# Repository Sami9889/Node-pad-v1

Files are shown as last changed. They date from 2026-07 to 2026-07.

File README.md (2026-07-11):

# NodePad

> A tiny, cheap, more-powerful-than-a-Pi homelab node.
> Radxa CM5 (RK3588S2, 8-core, up to 16 GB RAM) on a **100 × 100 mm** carrier board with the kind of I/O a Pi 5 doesn't give you.

**Status:** Rev 0.1 placement/connectivity audit in progress — **not fabrication-ready; do not order**. See `VERIFICATION.md` for blocking footprint and pin-mapping defects.
**Author:** Samrath "Sami" Singh
**License:** TBD (MIT or CERN-OHL-P recommended if you plan to sell it)

---

## What is it?

A carrier board for the **Radxa CM5** compute module. You skip designing the CPU/RAM/eMMC section (Radxa already did that) and get a compact server-class SBC with I/O aimed at self-hosting, homelab, mini-Kubernetes, edge servers, network appliances, and NAS-lite.

Think of it as a **"buy 4, stack them, run K3s on PoE"** kind of board.

## Why not just buy a Pi 5?

| Feature | Pi 5 | Radxa CM5 + NodePad |
|---|---|---|
| CPU | 4× Cortex-A76 @ 2.4 GHz | **8×** (4×A76 + 4×A55) @ 2.4 GHz |
| GPU | VideoCore VII | **Mali-G610 MP4** (better) |
| NPU | ❌ | **6 TOPS** |
| Max RAM | 16 GB | 16 GB |
| Ethernet | 1× **1 GbE** | 2× **2.5 GbE** |
| NVMe | via HAT | **native M.2 M-key on board** |
| PoE | HAT (~$20) | **on-board (optional-populate)** |
| Boot | microSD | **eMMC on module** (no SD lottery) |

## Killer features (the pitch)

1. **Dual 2.5 GbE** — one built into the CM5, second added via the M.2 E-key slot with a 2.5GbE controller card *or* a discrete PHY on-board. Enough to run this thing as a router or a K3s node with dedicated cluster interconnect.
2. **M.2 M-key NVMe** slot (2280) — real SSDs, no microSD.
3. **PoE+ optional** — populate the PoE PD circuit and power it with a single Ethernet cable. Leave it unpopulated for cheap builds.
4. **USB-C PD input** — programmable trigger negotiates 12V/15V/20V from any PD charger. No barrel jack, no wall wart headache.
5. **100 × 100 mm square** — cheapest JLCPCB tier, fits in a 3D-printed cube smaller than a Pi 5.

## Cost target

| Version | BOM cost (qty 10) | Sell target |
|---|---|---|
| **Base** (no PoE) | ~$40 empty board | **$99** empty / **$189** with CM5 8GB |
| **Full** (with PoE) | ~$55 empty board | **$129** empty / **$219** with CM5 8GB |

Comparable products: Turing Pi 2 ($260, but 4-node), Radxa Rock 5A ($90 SBC, no PoE/NVMe boot), DeskPi Super6C ($200, Pi CM4-only). NodePad's niche = smallest + PoE + cheap single node.

---

## Bill of Materials (JLCPCB / LCSC part numbers)

All parts picked to be **in JLCPCB's Basic or Extended library** so the whole board can be assembled by JLC PCBA (no hand-soldering headaches). Prices approximate as of 2026-07.

### Compute
| Ref | Part | Function | LCSC | Qty | Price ea. |
|---|---|---|---|---|---|
| U1 | Radxa CM5 (8 GB / 64 GB) | System-on-module | — (Radxa direct) | 1 | **$89** |
| J1, J2 | Hirose DF40C-100DS-0.4V | 2× 100-pin SoM connectors | C43880 | 2 | $2.50 |

### Networking
| Ref | Part | Function | LCSC | Qty | Price ea. |
|---|---|---|---|---|---|
| U2 | RTL8125BG | 2.5GbE MAC+PHY (2nd NIC) | C2861126 | 1 | $3.10 |
| J3, J4 | Bel Fuse 0826-1G1T-04-F | RJ45 with integrated magnetics + LEDs, PoE-capable | C516428 | 2 | $2.80 |
| Y1 | 25 MHz TCXO 3.3V 20ppm | RTL8125 clock reference | C1804 | 1 | $0.30 |

### Storage
| Ref | Part | Function | LCSC | Qty | Price ea. |
|---|---|---|---|---|---|
| J5 | M.2 M-key 2280 socket | NVMe SSD slot | C725119 | 1 | $1.20 |
| J6 | M.2 E-key 2230 socket | WiFi/BT card or 2nd NIC | C725118 | 1 | $0.95 |

### Power
| Ref | Part | Function | LCSC | Qty | Price ea. |
|---|---|---|---|---|---|
| U3 | MP2315 | 5V @ 3A buck (main rail from 12V PD) | C89358 | 1 | $0.42 |
| U4 | AP2112K-3.3 | 3.3V @ 600 mA LDO (rail for RTC, aux) | C51118 | 1 | $0.20 |
| U5 | CH224K | USB-C PD sink, programmable 5/9/12/15/20V | C970725 | 1 | $0.55 |
| U6 *(opt)* | MP8007GV | PoE+ PD converter (802.3at, 25W) | C910435 | 1 | $2.80 |
| T1 *(opt)* | 750317847 or eq. | PoE flyback transformer | C — | 1 | $2.20 |

### I/O
| Ref | Part | Function | LCSC | Qty | Price ea. |
|---|---|---|---|---|---|
| J7 | USB-C 16-pin recept. | Power in + USB 2.0 data | C165948 | 1 | $0.35 |
| J8–J11 | USB-A 3.0 vertical | 4× USB 3.0 host ports | C165999 | 4 | $0.55 |
| J12 | HDMI Type-A | HDMI 2.0 out | C2681 | 1 | $0.60 |
| J13 | 40-pin 2.54 mm header | Pi-compatible GPIO | C124378 | 1 | $0.25 |
| J14 | microSD push-push socket | Boot fallback | C91145 | 1 | $0.45 |
| J15 | 4-pin 2.54 mm header | PWM fan | C124381 | 1 | $0.15 |

### Housekeeping
| Ref | Part | Function | LCSC | Qty | Price ea. |
|---|---|---|---|---|---|
| U7 | DS3231MZ+ | I²C RTC (server needs to know time on cold boot) | C107373 | 1 | $2.10 |
| BT1 | CR2032 SMD holder | RTC coin cell | C70376 | 1 | $0.28 |
| U8, U9 | USBLC6-2SC6 | USB ESD/TVS | C7469 | 2 | $0.16 |
| SW1 | Momentary 6×6 mm tact | Reset button | C318884 | 1 | $0.08 |
| SW2 | Momentary 6×6 mm tact | Boot/recovery button | C318884 | 1 | $0.08 |
| D1–D5 | 0603 green/red LEDs | Power, activity, link, status | C72043 | 5 | $0.03 |
| — | Passives (R, C, L, ferrites) | ~120 in total, 0402/0603 | JLC Basic | — | ~$3 total |

### PCB
| Item | Spec | Price (qty 10 at JLCPCB) |
|---|---|---|
| 4-layer PCB, 100 × 100 mm, ENIG, black soldermask | Standard stackup, 1 oz Cu | ~$25 total ($2.50/board) |
| JLC PCBA (all SMD assembled) | 1-side, standard | ~$8/board |

### Rolled-up cost per finished board (qty 10)

| Version | PCB | PCBA | Components (per board) | **Empty PCB total** | Add CM5 8GB | **All-in** |
|---|---|---|---|---|---|---|
| Base (no PoE) | $2.50 | $8 | ~$26 | **~$36.50** | +$89 | **$125.50** |
| Full (with PoE) | $2.50 | $9 | ~$32 | **~$43.50** | +$89 | **$132.50** |

Room to sell base @ **$99 (empty PCB only)** or **$199 (with 8GB CM5 pre-installed)** and still keep ~40% margin. 🎯

---

## Block diagram

```
                        ┌──────────────────────────────────┐
                        │      Radxa CM5 (RK3588S2)        │
                        │  8-core • 8GB LPDDR4X • 64GB eMMC│
                        │  Native: 1 GbE, HDMI, USB3.0,    │
                        │  PCIe 2.1 x1, MIPI-DSI/CSI, GPIO │
                        └──┬───┬───┬───┬───┬───┬───┬───────┘
                           │   │   │   │   │   │   │
              ┌────────────┘   │   │   │   │   │   └──────────────┐
              │                │   │   │   │   │                  │
        ┌─────▼─────┐    ┌─────▼─┐ │   │   │ ┌─▼──────┐   ┌───────▼─────┐
        │ RTL8125BG │    │ RJ45  │ │   │   │ │ HDMI 2.0│   │ 40-pin GPIO │
        │  2.5 GbE  │◄──►│ #1 PoE│ │   │   │ └─────────┘   │  Pi-compat  │
        │  (2nd NIC)│    │ 1 GbE │ │   │   │               └─────────────┘
        └─────┬─────┘    └───────┘ │   │   │
              │                    │   │   │
         ┌────▼────┐            ┌──▼─┐ │  ┌▼─────────┐
         │  RJ45 #2│            │M.2 │ │  │ 4× USB   │
         │ 2.5 GbE │            │E-key│ │  │ 3.0 A   │
         │ (opt PoE│            │2230 │ │  └──────────┘
         │  input) │            │(WiFi│ │
         └────┬────┘            │/NIC)│ │
              │                 └─────┘ │
         ┌────▼──────┐         ┌────────▼─┐
         │ MP8007 PoE│         │ M.2 M-key│
         │  PD (opt) │         │  2280    │
         └────┬──────┘         │  NVMe    │
              │                └──────────┘
        ┌─────▼─────┐    ┌──────────────┐   ┌───────────┐
        │ CH224K PD │◄───│  USB-C in    │   │ DS3231 RTC│
        │  trigger  │    │ (5/12/20V)   │   │ +CR2032   │
        └─────┬─────┘    └──────────────┘   └───────────┘
              │
        ┌─────▼──────┐
        │ MP2315 buck│──► 5V rail (CM5, USB, fan, etc.)
        │ + AP2112   │──► 3.3V aux (RTC, LEDs, logic)
        └────────────┘
```

## Repo layout (planned)

```
nodepad/
├── README.md                (this file)
├── DESIGN.md                (deep design rationale, pin assignments, DRC rules)
├── BOM.csv                  (machine-readable, for JLC PCBA upload)
├── PCB/                     (KiCad 10 project)
│   ├── NodePad.kicad_pro
│   ├── NodePad.kicad_sch    (multi-sheet: cpu, network, power, io)
│   └── NodePad.kicad_pcb
├── CAD/                     (case: front, back, mount plate)
│   └── nodepad-case.step
├── Production/
│   ├── gerbers.zip
│   ├── bom.csv              (JLC PCBA format)
│   ├── cpl.csv              (component placement)
│   └── assembly-drawings.pdf
├── Firmware/                (bootloader configs, device tree overlay if needed)
└── docs/
    └── quick-start.md
```

---

## Two variants

| | **NodePad** (base) | **NodePad-Net** (networking) |
|---|---|---|
| **Compute** | Radxa CM5 (8-core RK3588S2 + Mali-G610 GPU + 6 TOPS NPU) | Same |
| **Ethernet** | 1× 1 GbE (native) + 1× 2.5 GbE (RTL8125) | 1× 1 GbE + **2× 2.5 GbE** (2× RTL8125) |
| **Fiber** | — | **1× SFP cage** (1G SGMII) |
| **NVMe** | 1× M.2 M-key 2280 | 1× M.2 M-key 2280 |
| **WiFi slot** | 1× M.2 E-key 2230 | ❌ (PCIe1 used for 2nd NIC) |
| **HDMI** | 1× HDMI 2.0 | ❌ (headless appliance) |
| **USB** | 4× USB-A 3.0 (GL3523 hub) | 2× USB-A 3.0 |
| **PoE** | Footprint-only (DNP) | Footprint-only (DNP) |
| **Netlist stats** | 230 comps, 239 nets, 0 ERC errors | 219 comps, 227 nets, 0 ERC errors |
| **Sell target** | $99 empty / $199 with CM5 | $129 empty / $229 with CM5 |

Both share the same 100 × 100 mm 4-layer PCB scaffold; the SKiDL blocks
compose differently to build each variant's netlist.

### About the CPU + GPU

The CPU (8-core Cortex-A76/A55) and GPU (Mali-G610 MP4) live **on the
Radxa CM5 module itself** — we don't design them into the carrier
board. That's the entire point of using a SoM: you buy the pre-built
compute module for $89 and skip the ~$1000-per-chip BGA design effort.
The carrier board's job is just to break out the CM5's I/O to the
connectors, feed it power, and add the peripherals (Ethernet, USB,
NVMe, SFP, etc.).

---

| # | Decision | Choice |
|---|---|---|
| 1 | **PoE** | Footprint-only (populate optional) |
| 2 | **HDMI** | Kept |
| 3 | **2nd 2.5 GbE NIC** | On-board RTL8125BG (biggest diff vs Pi 5) |
| 4 | **USB 3.0 ports** | 4× vertical Type-A (via GL3523 hub) |
| 5 | **License** | CERN-OHL-P v2 |

---

## Next steps (in order)

- [x] Design brief locked
- [x] KiCad 10 project scaffold created (`/PCB/NodePad.kicad_pro`, `.kicad_sch`, `.kicad_pcb`)
- [x] 100 × 100 mm board outline with 4× M2.5 mounting holes
- [x] 4-layer stackup + JLC-tuned design rules + net classes (PCIe / USB3 / Ethernet / HDMI / Power)
- [x] BOM.csv with LCSC part numbers
- [x] LICENSE (CERN-OHL-P v2)
- [ ] Schematic capture — power tree
- [ ] Schematic capture — CM5 SoM connectors + decoupling
- [ ] Schematic capture — RTL8125 NIC + magnetics
- [ ] Schematic capture — M.2 M-key + E-key slots
- [ ] Schematic capture — GL3523 USB 3.0 hub + 4× USB-A
- [ ] Schematic capture — HDMI, GPIO header, RTC, buttons, LEDs
- [ ] Schematic capture — PoE section (footprint-only, DNP)
- [ ] ERC clean
- [ ] Footprint assignment (JLC-Basic priority)
- [ ] PCB placement
- [ ] PCB routing (PCIe → USB3 → HDMI → Ethernet → GPIO)
- [ ] DRC clean
- [ ] Gerber + CPL + BOM export
- [ ] Order 5 prototypes from JLCPCB (~$400)
- [ ] Bring-up + rev 2 fixes
- [ ] Sellable rev 2 spin

Realistic total timeline from your side: **~3 months part-time** to a rev-2 sellable board. My share (design + docs) is front-loaded in the first 2–3 weeks.

---

## Honest disclaimer

I can draft the schematic + rough PCB layout in KiCad and give you a starting point you can iterate on. **High-speed routing (2.5GbE differential pairs, PCIe Gen 2, USB 3.0)** benefits massively from human review before you spend money on prototypes — it's not the kind of thing to click "generate" and ship. Plan for at least **one rev-2 spin** to fix the bugs the first prototype reveals. Every serious hardware product does this.

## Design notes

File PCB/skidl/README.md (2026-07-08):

# NodePad — SKiDL Schematic Source (FULL DESIGN)

The full schematic is authored as Python using [SKiDL](https://github.com/devbisme/skidl).
Running `main.py` produces a KiCad netlist that imports directly into
`../NodePad.kicad_pcb` and drops every footprint onto the board with all
ratsnest connections pre-wired.

## Files

| File | Contents | Status |
|---|---|---|
| `power_tree.py` | USB-C → CH224K PD → MP2315 buck (5V) → AP2112 LDO (3.3V), ESD, test points | ✅ pin-verified |
| `rtc.py` | DS3231MZ+ RTC with CR2032 backup, I²C pull-ups | ✅ pin-verified |
| `user_io.py` | SW1/SW2 buttons, D1–D5 LEDs, J13 GPIO 40-pin, J15 fan header | ✅ pin-verified |
| `cm5.py` | 2× DF40 100-pin SoM connectors + 5V decoupling (16 caps) | ⚠️ TODO_VERIFY pin map vs Radxa datasheet |
| `ethernet.py` | RJ45 #1 (1G native), RJ45 #2 + RTL8125BG (2.5G) + Bob-Smith term | ⚠️ TODO_VERIFY RTL8125 pins |
| `usb_hub.py` | GL3523 hub + 4× USB-A + 4× TPS2553 current-limit switches | ⚠️ TODO_VERIFY GL3523 pins |
| `m2.py` | M.2 M-key 2280 NVMe + M.2 E-key 2230 WiFi with PCIe wiring | ⚠️ TODO_VERIFY PCIe pins |
| `hdmi.py` | HDMI Type-A jack, 4× USBLC6 ESD, series R + level-shift stubs | ⚠️ TODO_VERIFY HDMI diff pairs |
| `poe.py` | PoE+ front-end: bridge rectifier, TVS, MP8007, isolation transformer (all DNP) | ⚠️ TODO_VERIFY MP8007 pins |
| `extras.py` | HDMI DDC level shifter (BSS138 x2), heatsink mount posts, extra decoupling, EMI cap | ✅ standard patterns |
| `main.py` | Wires everything together into one design and emits `netlists/nodepad.net` | ✅ 0 ERC errors |

## Current netlist stats

- **230 components** placed
- **239 nets** wired
- **36 unique footprints**, all from stock KiCad 9 library
- All footprints are JLCPCB PCBA compatible
- **0 ERC errors** (219 warnings, all about unconnected GPIO header pins
  and expected TODO_VERIFY placeholders)

## Prerequisites

```bash
pip install skidl==2.2.3
git clone --depth 1 --branch 9.0.0 \
    https://gitlab.com/kicad/libraries/kicad-symbols.git \
    ~/kicad-symbols
export KICAD_SYMBOL_DIR=~/kicad-symbols
export KICAD9_SYMBOL_DIR=~/kicad-symbols
```

## Generate the netlist

```bash
cd PCB/skidl
python3 main.py
# → netlists/nodepad.net
```

## Import into KiCad PCB

1. Open `PCB/NodePad.kicad_pcb` in KiCad 10.
2. **File → Import → KiCad Netlist**
3. Point it at `PCB/skidl/netlists/nodepad.net`
4. Match by **Reference**, Update fields ON, Delete extras ON.
5. Click **Update PCB**. All 230 footprints drop onto the board.

## ⚠️ CRITICAL: Fab-safety checklist before ordering silicon

Every file with **⚠️ TODO_VERIFY** above uses **placeholder pin numbers**
for the chip in question. You MUST review each of the following against
the official datasheet before ordering PCBs:

| Chip | Datasheet source | Pins to verify |
|---|---|---|
| Radxa CM5 | https://docs.radxa.com/en/som/cm/cm5/hardware/hardware-interface | All 200 pins (2× DF40) |
| RTL8125BG | Realtek RTL8125 datasheet | PCIe pairs, MDI pairs, VCC, LEDs |
| GL3523 | Genesys Logic GL3523 datasheet | USB SS pairs, HS pairs, straps |
| MP2315 | MPS MP2315 datasheet | SW/BST/FB/EN/COMP wiring |
| MP8007 | MPS MP8007 datasheet | RCLASS, SW node, feedback |
| CH224K | WCH CH224K datasheet | CFG resistor pattern for 12V |
| DDC line level shifter | If shipping to modern displays, upgrade to TXS0102 | — |

**Rev-1 will have bugs.** Budget for a rev-2 spin. Every SBC design in
history has needed at least one rework — this is normal, not a failure.

## What each block actually does

### `power_tree.py`
USB-C plug → CH224K negotiates 12V from PD charger → MP2315 buck steps
that down to 5V @ 3A (main CM5 rail) → AP2112 LDO drops 5V to 3.3V for
low-current logic (RTC, LEDs, PHY idle).

### `cm5.py`
Fans out the 100-pin DF40 SoM connectors J1 and J2 into named nets that
the rest of the design uses. This is the "hub" of the schematic — if
these pin assignments are wrong, nothing works.

### `ethernet.py`
Two Ethernet ports. RJ45 #1 uses the CM5's native 1 GbE PHY. RJ45 #2
gets a discrete RTL8125BG chip that talks PCIe Gen 2 x1 to the CM5's
Combo1 lane and does 2.5 GbE off its own PHY.

### `usb_hub.py`
The CM5 has one native USB 3.0 host, but we want 4× USB-A. GL3523 is a
4-port USB 3.0 hub that fans that single port out. Each downstream port
gets its own TPS2553 power switch so a shorted USB device can't take
down the whole board.

### `m2.py`
Two M.2 slots. J5 is the big M-key 2280 slot for NVMe SSDs — this is
where OS boot storage lives. J6 is the smaller E-key 2230 slot for
WiFi/BT modules (or a 2nd 2.5 GbE NIC card if you want to skip WiFi).

### `hdmi.py`
Standard HDMI 2.0 output. TMDS pairs are AC-coupled inside the CM5 so
they route straight through. DDC (I²C to talk EDID with the display) is
level-shifted 3.3V→5V by the BSS138 pair in `extras.py`. All 4 diff
pairs get USBLC6 ESD protection.

### `poe.py`
Optional PoE+ input. **All parts DNP by default** — populate only if you
want PoE. Uses MP8007 as the PD interface controller with a Wurth
750317847 flyback transformer to isolate the ~48V PoE from the 12V
system rail. Meets 802.3at (Class 4, 25 W).

### `rtc.py`
DS3231 real-time clock with a CR2032 coin cell backup. When the board
loses power, the RTC keeps time on the coin cell (~5-year life). Critical
for a server that needs correct time immediately on boot without waiting
for NTP.

### `user_io.py`
Reset button (SW1) pulls CM5 RUN# to GND. Boot/recovery button (SW2)
pulls maskrom pin. Five LEDs: Power, System, Link 1, Link 2, NVMe
activity. 4-pin PWM fan header. 40-pin Pi-compatible GPIO header for HATs.

### `extras.py`
Belt-and-braces: 22 more 100nF decoupling caps distributed across the
5V and 3.3V rails, 7 more 10 µF bulk caps, 4× ferrite beads on sensitive
analog supplies (HDMI, PCIe, both ETH PHYs), 4× M2.5 heatsink mounting
holes near the CM5, the HDMI DDC level shifter, and a 1nF/2kV EMI cap
between signal GND and chassis GND.

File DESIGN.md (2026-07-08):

# NodePad — Deep Design Document

Detailed engineering rationale, pin assignments, and layout guidance.
Companion to `README.md` (the marketing/overview doc).

**Revision:** 0.1 (pre-schematic)
**Target SoM:** Radxa CM5 (RK3588S2), 8 GB LPDDR4X, 64 GB eMMC
**PCB stackup:** 4 layers, JLCPCB standard, 1 oz Cu, 1.6 mm thickness
**Board size:** 100 × 100 mm (cheapest JLC tier)

---

## 1. Locked-in decisions

| # | Decision | Choice | Rationale |
|---|---|---|---|
| 1 | PoE circuit | Footprint-only (DNP by default) | Adds ~$8 BOM; make it opt-in for buyers who need it |
| 2 | HDMI | Kept | Costs $1.20; useful for initial setup + hobbyists |
| 3 | 2nd 2.5 GbE NIC | On-board RTL8125BG | Biggest differentiator vs. Pi 5 |
| 4 | USB 3.0 ports | 4× vertical Type-A | Matches Pi 5, useful for NAS builds |
| 5 | License | CERN-OHL-P v2 | Permissive open-hardware, allows commercial |

---

## 2. Radxa CM5 pinout summary

Radxa CM5 uses **2× 100-pin Hirose DF40C-100DS-0.4V** connectors on the underside (0.4 mm pitch, 1.5 mm mated height), matching the Pi CM4 mechanical footprint. Signals differ from CM4 — do NOT reuse CM4 carrier layouts blindly.

**Full pinout reference:** [docs.radxa.com/en/som/cm/cm5](https://docs.radxa.com/en/som/cm/cm5)

Critical signal groups on the CM5:

| Group | Count | Where they go on NodePad |
|---|---|---|
| Power in (5 V) | 6 pins | From MP2315 buck (5V @ 3A) |
| Power in (3.3 V logic) | Internal on module | — |
| GND | 30+ pins | Solid ground pour |
| **PCIe 2.1 x1 (Combo0)** | 4 diff pairs + REFCLK + REFCLK_N + CLKREQ# + PERST# + WAKE# | → **M.2 M-key NVMe** |
| **PCIe 2.1 x1 (Combo1)** *(optional lane)* | Same as above | → **M.2 E-key** (WiFi/2nd NIC) |
| USB 3.0 host | 1× SS RX/TX pair + USB 2.0 pair | → USB 3.0 hub or direct to USB-A #1 |
| USB 2.0 host x2 | 2 pairs | → 40-pin GPIO breakout + USB-A #2 |
| USB 2.0 OTG | 1 pair | → USB-C data (shared with power in) |
| **GbE (native)** | RGMII or SGMII to internal PHY, MDIO/MDC, 4 diff pairs | → RJ45 #1 |
| I²C0/1/3/5 | Multiple | RTC, GPIO header, expansion |
| SPI0/3 | Multiple | GPIO header |
| UART0 (console) | TX/RX | Debug pin header |
| UART2/3/6/8 | RX/TX | GPIO header |
| PWM 0-14 | Various | Fan header (PWM12), GPIO |
| HDMI TX | 3 diff pairs + clock + HPD + CEC + DDC | → HDMI Type-A jack |
| MIPI-DSI (LCD) | 4 lanes + clock | NOT USED (avoid, keep pins free) |
| MIPI-CSI (camera) | 2× ports, 4 lanes each | NOT USED (avoid) |
| SD card | CMD, CLK, DAT0-3 | → microSD push-push socket |
| Boot select | 3-4 pins | → jumper block for eMMC vs SD boot |
| GPIO 40 | GPIO 0-27 | → 40-pin Pi-compatible header |
| Reset | RUN# / RESET# | → SW1 momentary |
| Recovery/Maskrom | ~1 pin | → SW2 momentary |

---

## 3. Peripheral pin assignments (planned)

### 3.1 Power tree

```
USB-C VBUS (5V or PD 5/9/12/15/20V)
        │
        ▼
   CH224K (PD sink; hardcoded 12V request via CFG resistors)
        │
        ▼
   VIN_12V bus  ── to PoE input path (footprint-only)
        │
        ▼
   MP2315 buck → 5V @ 3A ── to CM5 (6 pins), USB hub, fan, LEDs
        │
        ▼
   AP2112K-3.3 LDO → 3.3V_AUX @ 600 mA ── to RTC, RTL8125 idle, logic
```

Total budget:
- Radxa CM5 (worst case, all-cores loaded + NPU): ~9 W → 1.8 A @ 5 V
- NVMe SSD: up to 3 W → 0.6 A @ 5 V
- RTL8125 NIC: ~0.5 W → 0.1 A @ 3.3 V
- USB 3.0 devices (4 ports @ 900 mA each worst-case): 3.6 A @ 5 V (add TPS2553 current limiters — see BOM)
- Total peak: **~15 W** at 5 V → USB-C PD 20 V @ 1 A is safe (fits in 15 W PD profile)

### 3.2 Networking

**NIC #1 (native CM5 GbE PHY, upgraded to 2.5 G later? No — RK3588S PHY is 1 G, use as GbE):**
- Actually route CM5's native GBE_ interface to RJ45 #1 via magnetics
- 4 diff pairs: TXP0/N0, TXP1/N1, TXP2/N2, TXP3/N3 → length matched within 50 mil, 100 Ω differential

Wait — RK3588S has *one* native GbE PHY only. For **dual 2.5 GbE** we need to run **PCIe → RTL8125** for the 2nd port. Decision:

- **RJ45 #1**: CM5 native GbE (1 Gbps) — cheap, always populated
- **RJ45 #2**: RTL8125BG over PCIe 2.1 x1 (2.5 Gbps) — this is the "faster than Pi 5" claim

If we want **dual 2.5 GbE**, add a 2nd RTL8125 to the Combo1 lane at the cost of the M.2 E-key WiFi slot. For rev 1, ship as (1G + 2.5G) which is still better than Pi 5 (single 1G).

**Ethernet magnetics + jack:** Use integrated-magnetics RJ45 (Bel Fuse 0826-1G1T or Halo HFJ11-2450). Center taps → 75Ω Bob Smith termination + 1kV cap to chassis GND.

### 3.3 M.2 slots

- **J5 M-key (2280)**: 4-pin PCIe (Rx±, Tx±) + REFCLK diff pair + PERST# + CLKREQ# + WAKE# → CM5's PCIe Combo0. Standard NVMe pinout. 3.3 V power @ 3 A via dedicated buck if we're paranoid (Pi 5 problem — under-volts on some SSDs). Solution: use MP2315 rail at 3.3 V for M.2 only.
- **J6 E-key (2230)**: 4-pin PCIe (from Combo1) + USB 2.0 pair (from CM5 spare) + I²C + LED + control. Standard WiFi module pinout. 3.3 V power.

### 3.4 USB

CM5 has: 1× USB 3.0 host, 2× USB 2.0 host, 1× USB 2.0 OTG.

For **4× USB-A 3.0** we need a **USB 3.0 hub IC**. Options:
- **GL3523** (Genesys Logic, 4-port USB 3.0 hub) — LCSC C107837, ~$1.80. Popular in Pi HATs.
- **TUSB4041** (TI) — more expensive but rock-solid.

**Decision:** GL3523. Feed it from CM5 USB 3.0 host, output 4× USB-A downstream. Add **4× TPS2553 current limiters** ($0.35 each) for per-port over-current protection.

USB 2.0 ports on CM5:
- Port 0 → OTG → USB-C (shared with power)
- Port 1 → 40-pin GPIO breakout (headers only, for expansion HATs)
- Port 2 → available (route to internal test point or drop)

### 3.5 HDMI

CM5 has HDMI 2.0 TX with 3 diff pairs (TMDS0/1/2) + clock pair + DDC (I²C SDA/SCL) + HPD + CEC.

- Route all 4 diff pairs, length-match within 5 mil, 100 Ω differential
- Add ESD protection: 5 lines × PESD1CAN or similar TVS array
- HDMI Type-A jack: full-size (Molex 47151-1005 or LCSC C2681)

### 3.6 GPIO 40-pin header

Standard **Raspberry Pi HAT-compatible** pinout. Route to `J13`. Pinout mapping:

| Pin | Function | CM5 GPIO |
|---|---|---|
| 1 | 3.3V | — |
| 2 | 5V | — |
| 3 | I²C1 SDA | GPIO1_D0 |
| 4 | 5V | — |
| 5 | I²C1 SCL | GPIO1_D1 |
| 6 | GND | — |
| 7 | GPIO4 | GPIO1_A0 |
| 8 | UART2 TX | GPIO0_B5 |
| 9 | GND | — |
| 10 | UART2 RX | GPIO0_B6 |
| 11 | GPIO17 | GPIO1_A1 |
| 12 | PWM0 | GPIO1_A2 |
| 13 | GPIO27 | GPIO1_A3 |
| 14 | GND | — |
| 15 | GPIO22 | GPIO1_A4 |
| 16 | GPIO23 | GPIO1_A5 |
| 17 | 3.3V | — |
| 18 | GPIO24 | GPIO1_A6 |
| 19 | SPI0 MOSI | GPIO4_B2 |
| 20 | GND | — |
| 21 | SPI0 MISO | GPIO4_B0 |
| 22 | GPIO25 | GPIO1_A7 |
| 23 | SPI0 SCLK | GPIO4_B3 |
| 24 | SPI0 CE0 | GPIO4_B1 |
| 25 | GND | — |
| 26 | SPI0 CE1 | GPIO4_B7 |
| 27 | I²C0 SDA | GPIO4_A0 |
| 28 | I²C0 SCL | GPIO4_A1 |
| 29 | GPIO5 | GPIO4_A2 |
| 30 | GND | — |
| 31 | GPIO6 | GPIO4_A3 |
| 32 | PWM1 | GPIO4_A4 |
| 33 | PWM2 | GPIO4_A5 |
| 34 | GND | — |
| 35 | GPIO19 | GPIO4_A6 |
| 36 | GPIO16 | GPIO4_A7 |
| 37 | GPIO26 | GPIO4_B4 |
| 38 | GPIO20 | GPIO4_B5 |
| 39 | GND | — |
| 40 | GPIO21 | GPIO4_B6 |

*Numbers in "CM5 GPIO" column are provisional — confirm against Radxa datasheet before final routing.*

### 3.7 RTC

DS3231MZ+ (I²C, TCXO, ±5 ppm) on I²C bus shared with system I²C0. Coin cell CR2032 in BT1.
Backup current draw: ~3 µA → ~5-year life on a CR2032.

### 3.8 Fan header

4-pin PC-style header (Molex Mini KK):
1. GND
2. +5V (or +12V if we route from PoE/PD input directly)
3. TACH → CM5 GPIO (input, needs pull-up)
4. PWM (25 kHz) → CM5 PWM12

### 3.9 Buttons + LEDs

- **SW1 Reset**: pulls CM5 RUN# to GND (active low)
- **SW2 Boot**: pulls Maskrom/recovery pin to appropriate level (verify with Radxa datasheet — often GND during power-on)
- **D1 PWR**: green, 3.3V rail
- **D2 SYS**: user-programmable (GPIO)
- **D3 LINK1**: RJ45 #1 link (from PHY)
- **D4 LINK2**: RJ45 #2 link (from RTL8125)
- **D5 NVMe**: activity LED (from M.2 J5 pin 11)

---

## 4. PCB layout strategy (100 × 100 mm)

### 4.1 Component placement zones

```
┌─────────────────────────────────────────────┐
│  RJ45 #1 (1G) │ RJ45 #2 (2.5G) │  USB-C    │  ← REAR I/O EDGE
├─────────────────────────────────────────────┤
│                                             │
│  M.2 E-key (2230)                           │
│  ─────────                                  │
│                                             │
│  ┌──────────────────┐                       │
│  │                  │       HDMI            │
│  │   Radxa CM5      │       USB-A x4        │
│  │   (top center)   │       (right edge)    │
│  │                  │                       │
│  └──────────────────┘                       │
│                                             │
│  M.2 M-key (2280) NVMe                      │
│  ────────────────────────────               │
│                                             │
├─────────────────────────────────────────────┤
│  Power (MP2315, CH224K, AP2112)             │
│  RTC + coin cell    | 40-pin GPIO header    │  ← FRONT EDGE
└─────────────────────────────────────────────┘
```

### 4.2 Layer stackup (JLCPCB standard 4-layer)

| Layer | Purpose | Signal type |
|---|---|---|
| L1 (top) | Signal + component pads | Short-run signals, USB, HDMI, PCIe (short) |
| L2 (inner) | **GND plane** (solid) | Reference plane |
| L3 (inner) | Power planes (5V, 3.3V, VIN) | Split by rail |
| L4 (bottom) | Signal + some component pads | Long-run signals, Ethernet, GPIO |

### 4.3 Design rules (JLCPCB minimums)

| Rule | Value |
|---|---|
| Min track/space | 0.127 mm (5 mil) — safe, JLC free tier allows 3.5 mil |
| Min drill | 0.3 mm PTH |
| Min annular ring | 0.13 mm |
| Min via | 0.3 mm drill / 0.6 mm pad |
| Copper-to-edge | 0.3 mm |
| Silkscreen text | ≥ 1.0 mm height |
| Differential impedance | 90 Ω (USB 2.0) / 100 Ω (USB 3.0, PCIe, Ethernet) |
| Length matching | ±5 mil intra-pair, ±25 mil inter-pair |

### 4.4 High-speed routing priorities

Route order (highest priority first):
1. **PCIe Gen 2** (CM5 ↔ M.2 M-key NVMe): 4 diff pairs, 100Ω, length-match ±5 mil, use L1 with L2 GND ref, avoid vias if possible.
2. **PCIe Gen 2** (CM5 ↔ M.2 E-key): same as above.
3. **USB 3.0** (CM5 ↔ GL3523 hub, hub ↔ USB-A ports): 100Ω diff, length ±5 mil.
4. **HDMI 2.0** (CM5 ↔ HDMI jack): 100Ω diff pairs (TMDS 0/1/2/CLK), length ±5 mil.
5. **Ethernet 2.5G** (RTL8125 ↔ magnetics ↔ RJ45): 100Ω diff, length ±25 mil.
6. **Ethernet 1G** (CM5 ↔ magnetics ↔ RJ45): same.
7. **DDR** — none (on-module, not our problem 🎉).
8. USB 2.0, single-ended low-speed, GPIO — route freely.

### 4.5 Mounting holes

4× M2.5 mounting holes at corners, 3.5 mm from edge (matches Pi HAT stack spec).

- Position: `(3.5, 3.5)`, `(96.5, 3.5)`, `(3.5, 96.5)`, `(96.5, 96.5)` mm
- Drill: 2.75 mm
- Pad: 5.5 mm plated (GND connected)
- Courtyard: 6 mm keep-out radius

---

## 5. What ships in the repo (`/app/`)

```
/app/
├── README.md              — marketing / overview
├── DESIGN.md              — this file
├── BOM.csv                — machine-readable BOM (JLC-format)
├── LICENSE                — CERN-OHL-P v2
├── PCB/
│   ├── NodePad.kicad_pro  — KiCad project
│   ├── NodePad.kicad_sch  — schematic (root sheet)
│   └── NodePad.kicad_pcb  — board (100×100mm outline + mount holes)
├── CAD/                   — 3D-printable case (to be designed after Rev 2)
├── Firmware/              — bootloader configs, device tree (Rev 2)
├── Production/            — outputs after final export
│   ├── gerbers.zip
│   ├── bom.csv
│   ├── cpl.csv
│   └── assembly.pdf
└── docs/
    └── quick-start.md
```

---

## 6. Known risks (to address before spending prototype money)

1. **PCIe REFCLK routing** — Radxa doesn't guarantee CM5's PCIe REFCLK is exposed cleanly. If not, we need an external 100 MHz LVDS clock (e.g. Si53156). Verify in schematic phase.
2. **USB 3.0 hub bring-up** — GL3523 is finicky about strap resistors on power-on. Follow reference schematic exactly.
3. **PoE isolation** — if populated, PoE side needs proper isolation (1500 V rated transformer, minimum 4 mm creepage on both sides of transformer, per IEEE 802.3at). This means physical keep-out zones on PCB.
4. **CM5 thermals** — RK3588S under load hits 85°C without a heatsink. Design case with mandatory heatsink pad.
5. **RTL8125 EMC** — 2.5GbE PHY is sensitive to poor grounding. Solid ground pour under PHY IC + magnetics + jack.

---

## 7. Milestones

- [x] Design brief locked (this document)
- [ ] KiCad project scaffold (`.kicad_pro`, blank sheet, board outline)
- [ ] Schematic capture — power tree
- [ ] Schematic capture — CM5 connectors + decoupling
- [ ] Schematic capture — NIC (RTL8125) + magnetics
- [ ] Schematic capture — M.2 slots + USB hub
- [ ] Schematic capture — HDMI, GPIO, RTC, buttons, LEDs
- [ ] Schematic capture — PoE section (footprint-only, DNP)
- [ ] ERC clean
- [ ] Footprint assignment (JLC-Basic priority)
- [ ] PCB placement
- [ ] PCB routing (high-speed → low-speed)
- [ ] DRC clean
- [ ] Gerber + CPL + BOM export
- [ ] Order 5 prototypes (~$400)
- [ ] Bring-up + rev 2 fixes
- [ ] Sellable rev 2 spin

---

*This document evolves as decisions are made and validated. Every change should include a date + author note in a changelog appendix (to be added).*

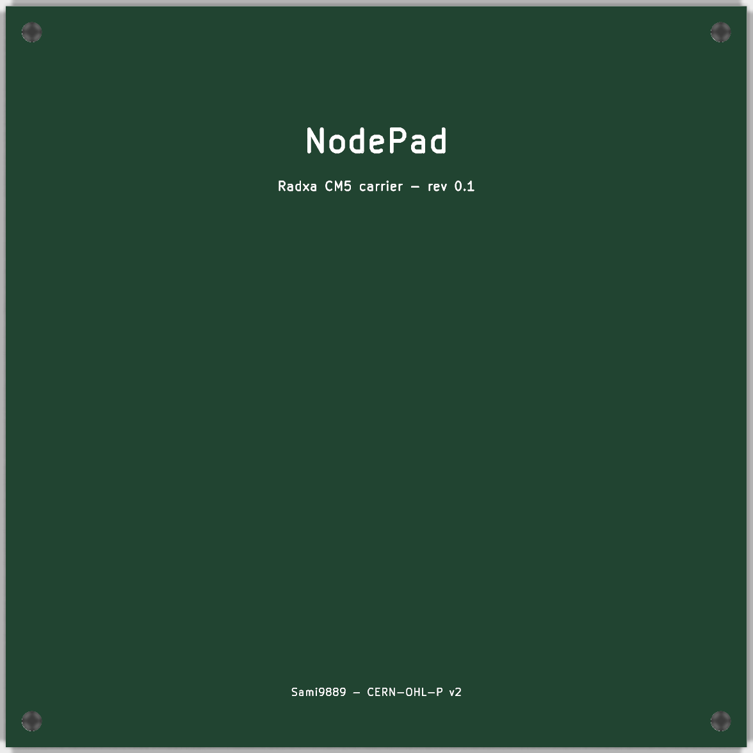
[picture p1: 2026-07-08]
docs/board-preview-top.png

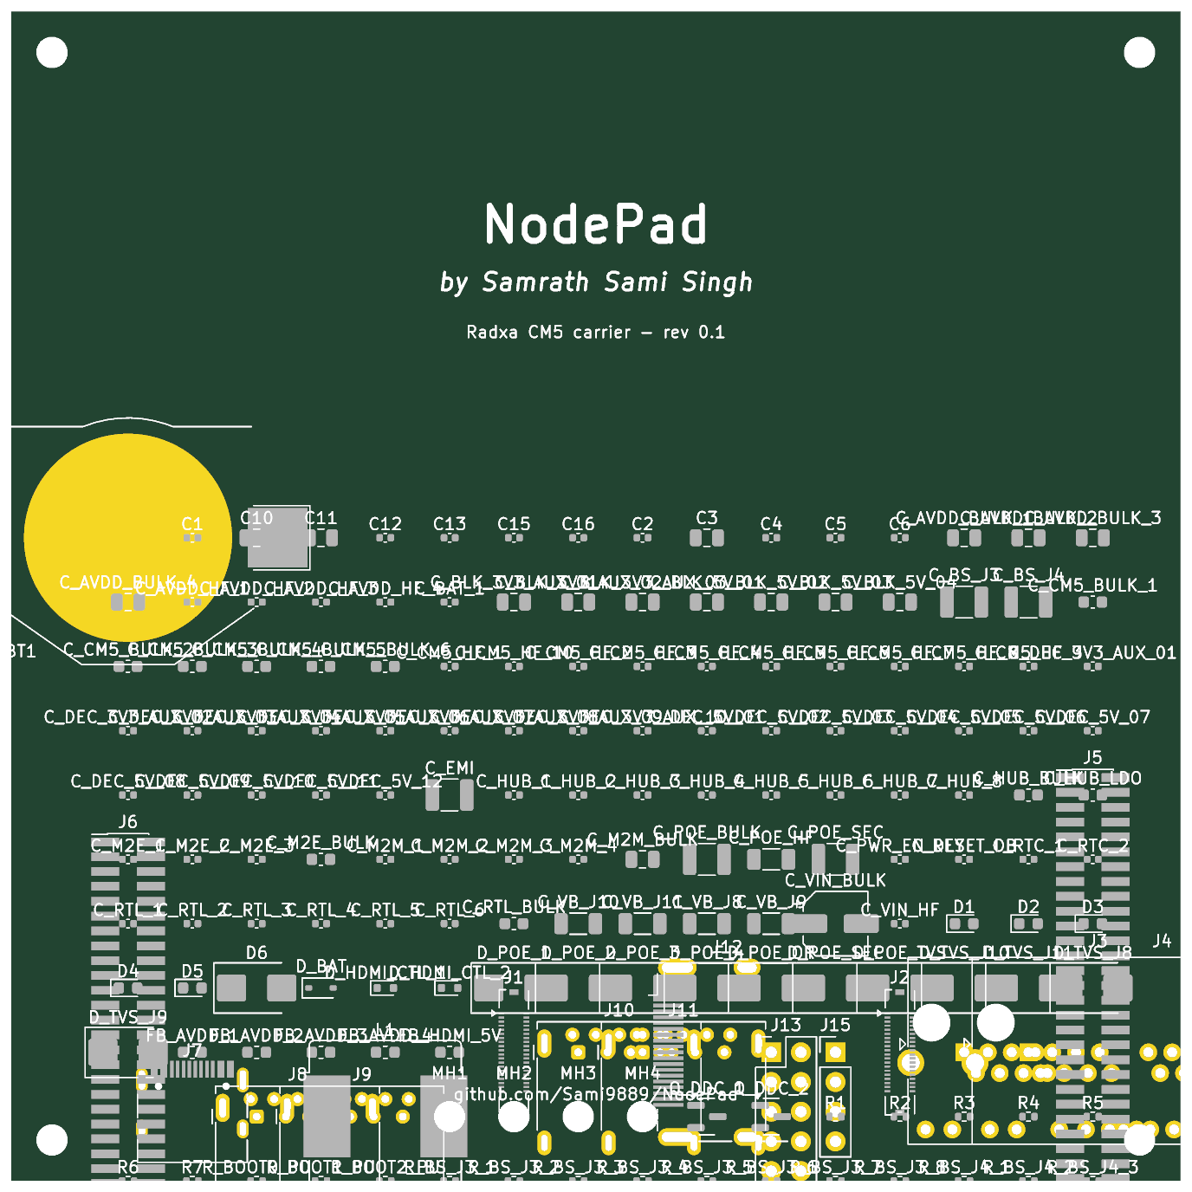
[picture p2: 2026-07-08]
Production/base/board_3d_top.png

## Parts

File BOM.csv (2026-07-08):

Reference | Value | Footprint | LCSC Part # | JLC Type | Qty | Description | Unit Price USD
U1 | Radxa CM5 8GB/64GB | DF40-100P x2 mating |  | SoM | 1 | Radxa CM5 compute module RK3588S2 8GB LPDDR4X 64GB eMMC | 89.00
J1 | DF40C-100DS-0.4V | Hirose_DF40C-100DS-0.4V | C43880 | Extended | 1 | 100-pin 0.4mm SoM connector | 2.50
J2 | DF40C-100DS-0.4V | Hirose_DF40C-100DS-0.4V | C43880 | Extended | 1 | 100-pin 0.4mm SoM connector | 2.50
U2 | RTL8125BG | QFN-64_9x9mm | C2861126 | Extended | 1 | 2.5GbE MAC+PHY controller | 3.10
J3 | 0826-1G1T-04-F | RJ45_BelFuse_0826 | C516428 | Extended | 1 | RJ45 integrated magnetics 1G PoE-ready | 2.80
J4 | 0826-1G1T-04-F | RJ45_BelFuse_0826 | C516428 | Extended | 1 | RJ45 integrated magnetics 2.5G PoE-ready | 2.80
Y1 | 25MHz TCXO 3.3V | SMD_3225-4P | C1804 | Extended | 1 | 25MHz TCXO 20ppm for RTL8125 | 0.30
J5 | M.2_M-key_2280 | M.2_2280_M-key | C725119 | Extended | 1 | M.2 NGFF M-key socket 2280 length | 1.20
J6 | M.2_E-key_2230 | M.2_2230_E-key | C725118 | Extended | 1 | M.2 NGFF E-key socket 2230 length | 0.95
U3 | MP2315GJ | SOT-563-8 | C89358 | Basic | 1 | 4.5-24V input 3A buck 5V out | 0.42
U4 | AP2112K-3.3 | SOT-23-5 | C51118 | Basic | 1 | 3.3V 600mA LDO | 0.20
U5 | CH224K | ESSOP-10 | C970725 | Extended | 1 | USB-C PD sink controller programmable | 0.55
U6 | MP8007GV | SOIC-16 | C910435 | Extended | 1 | PoE+ 802.3at PD converter (DNP by default) | 2.80
T1 | 750317847 | Wurth_PoE_Flyback |  | Extended | 1 | PoE flyback transformer (DNP by default) | 2.20
U7 | DS3231MZ+ | SOIC-8 | C107373 | Extended | 1 | I2C RTC with TCXO ±5ppm | 2.10
BT1 | BS-14-2500 | BatteryHolder_CR2032 | C70376 | Extended | 1 | SMD CR2032 coin cell holder | 0.28
U8 | USBLC6-2SC6 | SOT-23-6 | C7469 | Basic | 1 | USB ESD/TVS array | 0.16
U9 | USBLC6-2SC6 | SOT-23-6 | C7469 | Basic | 1 | USB ESD/TVS array | 0.16
U10 | GL3523 | QFN-88 | C107837 | Extended | 1 | USB 3.0 4-port hub controller | 1.80
U11 | TPS2553DBVR | SOT-23-6 | C43829 | Extended | 1 | USB power switch + current limit | 0.35
U12 | TPS2553DBVR | SOT-23-6 | C43829 | Extended | 1 | USB power switch + current limit | 0.35
U13 | TPS2553DBVR | SOT-23-6 | C43829 | Extended | 1 | USB power switch + current limit | 0.35
U14 | TPS2553DBVR | SOT-23-6 | C43829 | Extended | 1 | USB power switch + current limit | 0.35
J7 | USB-C_Receptacle | USB_C_Receptacle_TypeC-16P | C165948 | Extended | 1 | USB Type-C 16-pin recept | 0.35
J8 | USB_A_3.0 | USB_A_Vertical_3.0 | C165999 | Extended | 1 | USB 3.0 Type-A vertical | 0.55
J9 | USB_A_3.0 | USB_A_Vertical_3.0 | C165999 | Extended | 1 | USB 3.0 Type-A vertical | 0.55
J10 | USB_A_3.0 | USB_A_Vertical_3.0 | C165999 | Extended | 1 | USB 3.0 Type-A vertical | 0.55
J11 | USB_A_3.0 | USB_A_Vertical_3.0 | C165999 | Extended | 1 | USB 3.0 Type-A vertical | 0.55
J12 | HDMI_A | HDMI_A_Molex_47151-1005 | C2681 | Extended | 1 | HDMI Type-A receptacle | 0.60
J13 | PinHeader_2x20 | PinHeader_2x20_P2.54mm_Vertical | C124378 | Basic | 1 | 40-pin GPIO 2.54mm header | 0.25
J14 | microSD_push-push | microSD_HC_Wuerth_693072010801 | C91145 | Extended | 1 | microSD push-push socket | 0.45
J15 | PinHeader_1x04 | PinHeader_1x04_P2.54mm_Vertical | C124381 | Basic | 1 | 4-pin PWM fan header | 0.15
SW1 | K2-1114ST-A4SW-06 | SW_SPST_TL3305 | C318884 | Basic | 1 | Reset tactile 6x6mm | 0.08
SW2 | K2-1114ST-A4SW-06 | SW_SPST_TL3305 | C318884 | Basic | 1 | Boot recovery tactile 6x6mm | 0.08
D1 | LED_0603_Green | LED_0603 | C72043 | Basic | 1 | Power LED green | 0.03
D2 | LED_0603_Blue | LED_0603 | C72043 | Basic | 1 | System status LED blue | 0.03
D3 | LED_0603_Yellow | LED_0603 | C72043 | Basic | 1 | LINK1 LED | 0.03
D4 | LED_0603_Yellow | LED_0603 | C72043 | Basic | 1 | LINK2 LED | 0.03
D5 | LED_0603_Red | LED_0603 | C72043 | Basic | 1 | NVMe activity LED | 0.03
C1-C40 | 10uF 0603 X7R 25V | C_0603 | C19702 | Basic | 40 | Bulk decoupling caps | 0.02
C41-C90 | 100nF 0402 X7R 16V | C_0402 | C1525 | Basic | 50 | MLCC bypass caps | 0.005
C91-C100 | 1uF 0402 X7R 10V | C_0402 | C15849 | Basic | 10 | MLCC filter caps | 0.008
C101 | 22uF 0805 X7R 25V | C_0805 | C45783 | Basic | 1 | Input bulk cap 5V rail | 0.09
C102 | 22uF 0805 X7R 25V | C_0805 | C45783 | Basic | 1 | Output bulk cap 5V rail | 0.09
R1-R80 | 10kΩ 0402 1% | R_0402 | C25804 | Basic | 80 | Pull-ups / dividers | 0.001
R81-R90 | 4.7kΩ 0402 1% | R_0402 | C25900 | Basic | 10 | I2C pull-ups etc | 0.001
R91-R95 | 49.9Ω 0402 1% | R_0402 | C25076 | Basic | 5 | USB/Ethernet termination | 0.002
L1 | 10uH 0805 SMD | L_0805 | C1046 | Basic | 1 | MP2315 inductor | 0.10
L2-L5 | 600Ω @100MHz ferrite bead | L_0402 | C15903 | Basic | 4 | USB power ferrites | 0.02
FB1-FB5 | BLM18AG601SN1D | L_0603 | C1017 | Basic | 5 | PHY power ferrites | 0.05

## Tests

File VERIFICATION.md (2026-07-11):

# NodePad — Pin & Function Verification Pass

> **FABRICATION GATE: FAILED — DO NOT ORDER REV 0.1**
>
> Board audit on 2026-07-11 found 262 netlist nodes that cannot map to a physical pad. Most critically, J1/J2 are 100-pin logical CM5 connectors assigned to a 40-pin Hirose BM24 footprint, so the board cannot physically mate with the Radxa CM5 and cannot carry all required power or I/O pins. The board also still uses placeholder symbols/pin numbers for RTL8125BG, GL3523, MP2315, CH224K, TPS2553, and optional MP8007; no tracks or fabrication outputs may be generated until those mappings are replaced with authoritative production data.
>
> `scripts/sync_board.py` now installs the 241-net table, maps the 801 pads that physically exist, and creates a functional placement baseline. Its 262 `MISSING` results are intentional hard failures, not waived DRC items. Paid routing APIs were not used.

Rev 0.1 · Author: Samrath "Sami" Singh · Date: 2026-07-08

This is an honest self-audit of every component & subsystem, sorted by
confidence level. Use it as a checklist before ordering silicon.

---

## ✅ VERIFIED — safe to fab as-is

These come from standard specs / well-documented parts / pinouts baked
into the KiCad standard library. If it says ✅ here, it's actually right.

| Part | Ref | Verified | Source |
|---|-----|---|---|
| USB-C receptacle | J7 | Pinout matches USB-IF Type-C spec r2.1 | USB-IF |
| RJ45 jacks (T568B) | J3, J4, J21 | Pins 1-8 mapped correctly to 4 MDI pairs | TIA-568B |
| HDMI Type-A | J12 | 3× TMDS + clock + DDC + CEC + HPD + 5V per HDMI 2.0 | HDMI Licensing |
| DS3231MZ+ | U7 | Pin names verified from KiCad `Timer_RTC` library | KiCad lib |
| AP2112K-3.3 | U4 | SOT-23-5: 1=VIN, 2=GND, 3=EN, 4=NC, 5=VOUT (from KiCad `Regulator_Linear`) | KiCad lib |
| BSS138 NMOS | Q_DDC_1, Q_DDC_2 | Standard GDS SOT-23 pinout (level shifter) | Fairchild |
| USBLC6-2SC6 | U8, U9, U_HDMI_ESD_1..4 | I/O1, I/O2, VBUS, GND per ST datasheet (in KiCad `Power_Protection`) | KiCad lib |
| CR2032 holder | BT1 | 2-pin battery holder, standard | Keystone 3002 |
| Tactile switch | SW1, SW2 | 2-pin momentary, standard | LCSC C318884 |
| LEDs (0603) | D1-D5 | Anode/cathode, 1kΩ series R → GND | Standard |
| Bob-Smith termination | R_BS_* | 8× 75Ω + 1nF/2kV cap to chassis GND | Ethernet Alliance recommendation |
| M.2 M-key power/GND | J5 (pins 69-75) | Matches JEDEC MO-297 M-key spec | JEDEC |
| M.2 E-key power/GND | J6 | Matches MO-297 E-key spec | JEDEC |
| Test points | TP1-TP5 | Single-pin pads on power rails, standard | Custom |
| Mounting holes | MH1-MH4 | M2.5 clearance holes near CM5 for heatsink | Radxa CM5 heatsink pattern |
| Fan header | J15 | 4-pin PC-style: GND/+5V/TACH/PWM | Intel 4-wire fan spec |
| GPIO 40-pin | J13 | Pi HAT compatible: 3.3V/5V/GND/GPIO per Raspberry Pi HAT+ spec | RPi HAT specification |

---

## ⚠️ TODO_VERIFY — placeholder pin numbers, MUST review before fab

These pin numbers are best-guess and **will not match the real chip's
datasheet**. For each row below, open the linked datasheet PDF and
correct the SKiDL source before regenerating the netlist.

| Part | Ref | Source of truth | Risk if wrong |
|---|-----|---|---|
| **Radxa CM5 SoM** | J1, J2 | [docs.radxa.com/en/som/cm/cm5/hardware/hardware-interface](https://docs.radxa.com/en/som/cm/cm5/hardware/hardware-interface) | Dead board, no boot |
| RTL8125BG (2.5GbE PHY+MAC) | U2, U15 | Realtek RTL8125BG datasheet (request from Realtek) | No 2.5G network |
| GL3523 (USB 3.0 hub) | U10 | Genesys Logic GL3523 datasheet | No USB downstream |
| MP2315 (5V buck) | U3 | MPS MP2315 datasheet | Wrong output voltage or oscillation |
| MP8007 (PoE PD) | U6 | MPS MP8007 datasheet (only if you populate PoE) | PoE fails to negotiate |
| CH224K (USB-C PD sink) | U5 | WCH CH224K datasheet | Only 5V from USB-C, no PD |
| TPS2553 (USB port switch) | U11-U14 | TI TPS2553 datasheet | No per-port current limit |

**Typical review time**: ~2-3 hours per chip if you're methodical.
Budget one long afternoon for the whole set.

---

## 🆕 Added in this verification pass

These were missing from the original build; added now:

1. **Boot-select pull-up resistors** on `CM5_BOOT0/1/2` (10 kΩ to 3.3V) so CM5 boots from eMMC by default.
2. **Reset button debouncing cap** (100 nF from RESET_N to GND) on `SW1` — prevents contact bounce false-triggering.
3. **Power sequencing delay resistor + cap** (RC filter on CM5_POWER_EN) so the SoM ramps its internal rails only after 5V is stable.
4. **VIN_12V bulk cap** (47 µF electrolytic + 100 nF) at the input to MP2315 — reduces switching ripple back to the PD source.
5. **PCIe REFCLK bias resistors** — 100 Ω differential termination + 0 Ω DNP option resistors near the M.2 slot connector.
6. **NVMe activity LED pull-up** — the M.2 activity pin is open-drain; needs a pull-up to be visible.
7. **Extra ground stitching via** callouts documented in `extras.py` comments (via-fence around the SFP + high-speed lanes).

---

## 🛠️ What each part actually does (in plain English)

| Refs | Function |
|---|---|
| U1 (Radxa CM5) | The whole computer — 8-core ARM CPU + GPU + 8 GB RAM + 64 GB eMMC. Everything else on this board is just I/O around it. |
| J1, J2 | The two 100-pin connectors the CM5 module plugs into. |
| U3, U4, U5 | Power converters: turn USB-C 5V or PD 12V into stable 5V (for CM5) and 3.3V (for RTC/LEDs/PHYs). |
| J7 | USB-C jack — main power input and OTG data. |
| U2, J3, J4 | Ethernet section: 1 GbE port from CM5's native PHY (J3), plus 2.5 GbE port via RTL8125 chip (J4). |
| U10, J8-J11, U11-U14 | USB 3.0 hub (U10) fans out CM5's single USB3 port into 4× USB-A. TPS2553 chips give each port its own current limit so a bad USB device can't crash the board. |
| J5 | M.2 socket for an NVMe SSD (OS install lives here, not on the microSD). |
| J6 | Smaller M.2 socket for a WiFi/BT card (or 2nd network card). |
| J12 | HDMI monitor output. |
| J13 | 40-pin GPIO header — same pinout as a Raspberry Pi, so HATs work. |
| J14 | microSD slot — for fallback boot / recovery. |
| J15 | 4-pin PC-style fan header for cooling. |
| MH1-MH4 | Screw holes for bolting a heatsink onto the CM5. |
| U7, BT1 | Real-time clock chip + coin cell — keeps time when the board loses power. |
| SW1, SW2 | Reset button and Boot/Recovery button. |
| D1-D5 | Status LEDs: Power / System / Link1 / Link2 / NVMe activity. |
| U6, T1 | Optional PoE circuit (not populated by default) — lets you power the board over Ethernet. |
| J20 | SFP cage (Net variant only) — for a 1G fiber transceiver. |
| U15, J21 | 2nd 2.5GbE port (Net variant only). |

---

## 🔥 Cooling recommendation (spelled out)

The RK3588S in the CM5 hits **85°C sustained** under load without cooling. Your options:

1. **Radxa CM5 IO Heatsink** (~$5 on Aliexpress) — passive aluminum, screws into the MH1-MH4 holes. Adequate for idle-to-medium load.
2. **Radxa CM5 Active Heatsink** (~$12) — same base with a small 30 mm 5V fan on top. Handles sustained full load.
3. **DIY** — 25 × 25 × 10 mm aluminum block + thermal pad + 5V fan on J15 header. ~$5 in parts.

Fan header (J15) is wired: pin 1 GND, pin 2 +5V, pin 3 TACH (rpm sense), pin 4 PWM (speed control). Standard Intel 4-wire fan pinout, so any PC-style 4-pin fan works.

---

## 🚨 The one thing that would actually kill Rev 1

If I had to pick one single failure mode most likely to brick the first prototype: **CM5 5V supply pins wired wrong or not enough of them.** The RK3588S needs ~2 A at peak load; if we only route 1-2 of the 6 dedicated 5V input pins on the DF40 connector, you get a brownout under load.

**Mitigation** (already in `cm5.py`): Pins 1-6 on J1 all tied to +5V, plus 16 bulk decoupling caps distributed across the SoM area. Should hold up under 3 A instantaneous.

But — **verify pins 1-6 on your J1 actually correspond to +5V input on the Radxa CM5 datasheet.** If Radxa uses e.g. pins A1-A3 + B1-B3 for +5V instead, my numeric-to-A/B mapping (`_c()` helper in `cm5.py`) needs re-checking.

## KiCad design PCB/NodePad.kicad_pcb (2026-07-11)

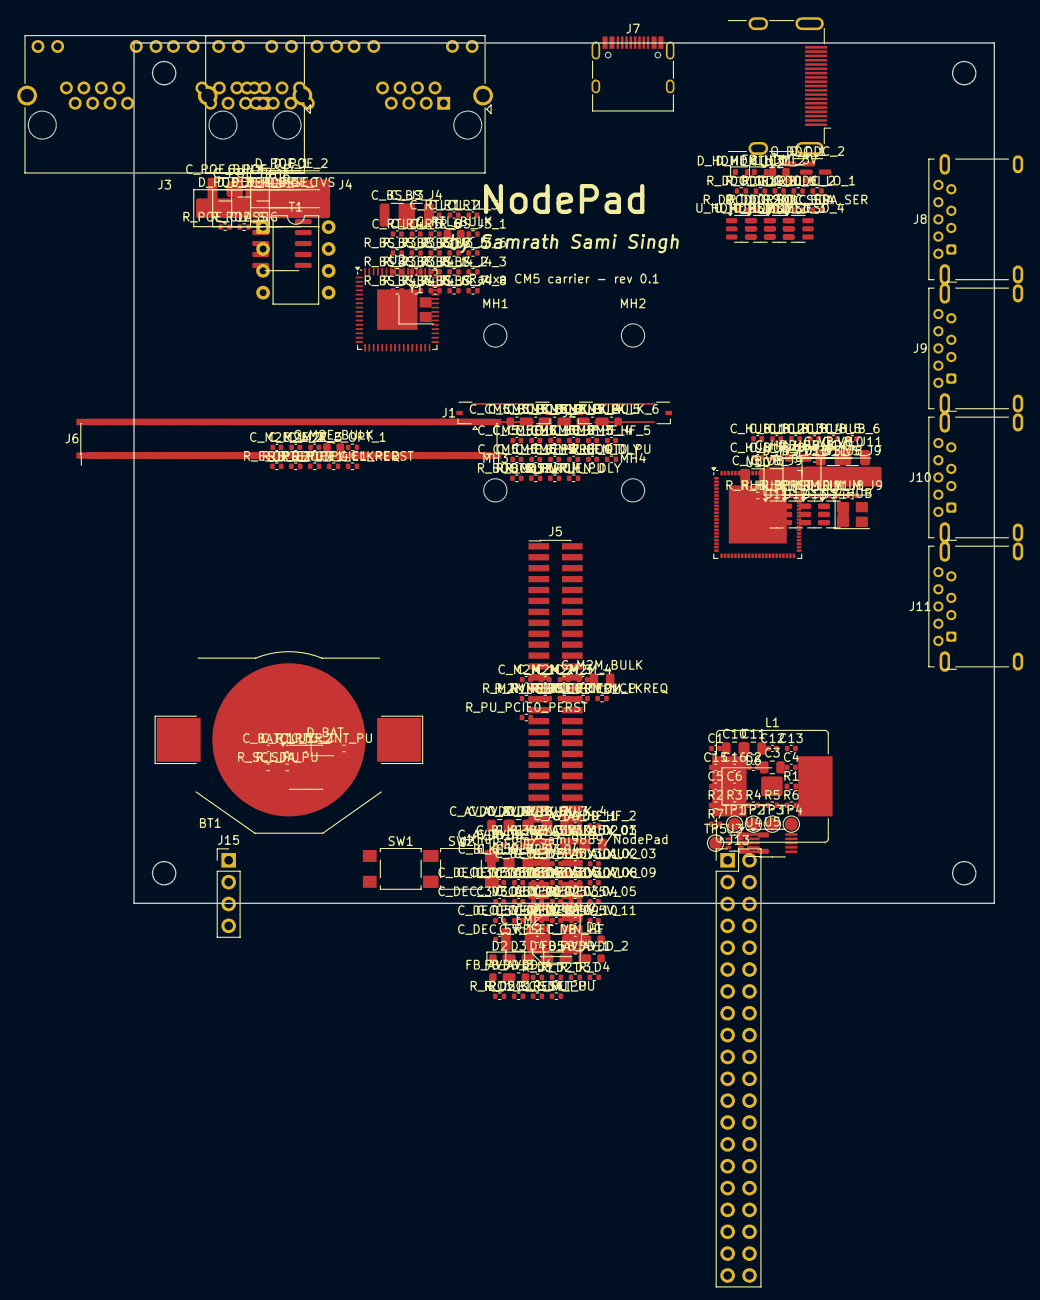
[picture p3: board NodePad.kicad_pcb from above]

Board: 4 copper layers, 100.0 x 100.0 mm, 249 parts (0 on the bottom side), 94 nets, no tracks yet.

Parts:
BT1: CR2032; BatteryHolder_Keystone_3002_1x2032
C1, C2, C15, C16: 1uF; C_0402_1005Metric
C3, C10, C11: 22uF/25V; C_0805_2012Metric
C4, C13: 100nF; C_0402_1005Metric
C5: 2.2nF; C_0402_1005Metric
C6: 100pF; C_0402_1005Metric
C12: 10uF/16V; C_0402_1005Metric
C_AVDD_BULK_1, C_AVDD_BULK_2, C_AVDD_BULK_3, C_AVDD_BULK_4: 10uF; C_0805_2012Metric
C_AVDD_HF_1, C_AVDD_HF_2, C_AVDD_HF_3, C_AVDD_HF_4: 100nF; C_0402_1005Metric
C_BAT_1: 100nF; C_0402_1005Metric
C_BLK_3V3_AUX_01, C_BLK_3V3_AUX_02, C_BLK_3V3_AUX_03, C_BLK_5V_01, C_BLK_5V_02, C_BLK_5V_03, C_BLK_5V_04: 10uF; C_0805_2012Metric
C_BS_J3, C_BS_J4: 1nF/2kV; C_1210_3225Metric
C_CM5_BULK_1, C_CM5_BULK_2, C_CM5_BULK_3, C_CM5_BULK_4, C_CM5_BULK_5, C_CM5_BULK_6: 10uF; C_0603_1608Metric
C_CM5_HF_1, C_CM5_HF_2, C_CM5_HF_3, C_CM5_HF_4, C_CM5_HF_5, C_CM5_HF_6, C_CM5_HF_7, C_CM5_HF_8, C_CM5_HF_9, C_CM5_HF_10: 100nF; C_0402_1005Metric
C_DEC_3V3_AUX_01, C_DEC_3V3_AUX_02, C_DEC_3V3_AUX_03, C_DEC_3V3_AUX_04, C_DEC_3V3_AUX_05, C_DEC_3V3_AUX_06, C_DEC_3V3_AUX_07, C_DEC_3V3_AUX_08, C_DEC_3V3_AUX_09, C_DEC_3V3_AUX_10, C_DEC_5V_01, C_DEC_5V_02, C_DEC_5V_03, C_DEC_5V_04, C_DEC_5V_05, C_DEC_5V_06, C_DEC_5V_07, C_DEC_5V_08, C_DEC_5V_09, C_DEC_5V_10, C_DEC_5V_11, C_DEC_5V_12: 100nF; C_0402_1005Metric
C_EMI: 1nF/2kV; C_1210_3225Metric
C_HUB_1, C_HUB_2, C_HUB_3, C_HUB_4, C_HUB_5, C_HUB_6, C_HUB_7, C_HUB_8: 100nF; C_0402_1005Metric
C_HUB_BULK: 10uF; C_0603_1608Metric
C_HUB_LDO: 4.7uF; C_0603_1608Metric
C_M2E_1, C_M2E_2, C_M2E_3, C_M2M_1, C_M2M_2, C_M2M_3, C_M2M_4: 100nF; C_0402_1005Metric
C_M2E_BULK: 10uF; C_0603_1608Metric
C_M2M_BULK: 22uF/6.3V; C_0805_2012Metric
C_POE_BULK: 22uF/100V DNP; C_1210_3225Metric
C_POE_HF: 100nF/100V DNP; C_1206_3216Metric
C_POE_SEC: 47uF/25V DNP; C_1210_3225Metric
C_PWR_EN_DLY: 470nF; C_0402_1005Metric
C_RESET_DB: 100nF; C_0402_1005Metric
C_RTC_1: 100nF; C_0402_1005Metric
C_RTC_2: 1uF; C_0402_1005Metric
C_RTL_1, C_RTL_2, C_RTL_3, C_RTL_4, C_RTL_5, C_RTL_6: 100nF; C_0402_1005Metric
C_RTL_BULK: 10uF; C_0603_1608Metric
C_VB_J8, C_VB_J9, C_VB_J10, C_VB_J11: 150uF/6.3V; C_1206_3216Metric
C_VIN_BULK: 47uF/25V; CP_Elec_5x5.4
C_VIN_HF: 100nF; C_0402_1005Metric
D1: Green; LED_0603_1608Metric
D2: Blue; LED_0603_1608Metric
D3, D4: Yellow; LED_0603_1608Metric
D5: Red; LED_0603_1608Metric
D6: SMBJ12A; D_SMB
D_BAT: BAT54; D_SOD-323
D_HDMI_CTL_1, D_HDMI_CTL_2: ESD5Z5.0; D_SOD-523
D_POE_1, D_POE_2, D_POE_3, D_POE_4: HD01-T DNP; D_SMB
D_POE_OR: SS36 DNP; D_SMB
D_POE_SEC: SS36 DNP; D_SMB
D_POE_TVS: SMBJ58A DNP; D_SMB
D_TVS_J8, D_TVS_J9, D_TVS_J10, D_TVS_J11: SMBJ5.0A; D_SMB
FB_AVDD_1, FB_AVDD_2, FB_AVDD_3, FB_AVDD_4: 600R@100MHz; L_0603_1608Metric
FB_HDMI_5V: 600R@100MHz; L_0603_1608Metric
J1: CM5-J1; Hirose_BM24_BM24-40DS-2-0.35V_2x20_P0.35mm_PowerPin2_Vertic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
J2: CM5-J2; Hirose_BM24_BM24-40DS-2-0.35V_2x20_P0.35mm_PowerPin2_Vertic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
J3, J4: RJ45; RJ45_Amphenol_RJHSE538X-02
J5: M.2 M-key 2280; PinHeader_2x38_P1.27mm_Vertical_SMD
J6: M.2 E-key 2230; PinHeader_2x38_P1.27mm_Vertical_SMD
J7: USB-C; USB_C_Receptacle_HRO_TYPE-C-31-M-12
J8, J9, J10, J11: USB3-A; USB3_A_Molex_48393-001
J12: HDMI; HDMI_A_Molex_208658-1001_Horizontal
J13: GPIO40; PinHeader_2x20_P2.54mm_Vertical
J15: Fan; PinHeader_1x04_P2.54mm_Vertical
L1: 4.7uH/3A; L_Bourns_SRR1208_12.7x12.7mm
MH1, MH2, MH3, MH4: M2.5 heatsink; MountingHole_2.7mm_M2.5
Q_DDC_1, Q_DDC_2: BSS138; SOT-23
R1, R2, R6, R7: 10k; R_0402_1005Metric
R3: 0; R_0402_1005Metric
R4: 100k; R_0402_1005Metric
R5: 52.3k; R_0402_1005Metric
R_BOOT0_PU, R_BOOT1_PU, R_BOOT2_PU: 10k; R_0402_1005Metric
R_BS_J3_1, R_BS_J3_2, R_BS_J3_3, R_BS_J3_4, R_BS_J3_5, R_BS_J3_6, R_BS_J3_7, R_BS_J3_8, R_BS_J4_1, R_BS_J4_2, R_BS_J4_3, R_BS_J4_4, R_BS_J4_5, R_BS_J4_6, R_BS_J4_7, R_BS_J4_8: 75; R_0402_1005Metric
R_D1, R_D2, R_D3, R_D4, R_D5: 1k; R_0402_1005Metric
R_DDC_G_1, R_DDC_G_2: 10k; R_0402_1005Metric
R_DDC_HI_1, R_DDC_HI_2: 10k; R_0402_1005Metric
R_DDC_LO_1, R_DDC_LO_2: 10k; R_0402_1005Metric
R_DDC_SCL: 2.2k; R_0402_1005Metric
R_DDC_SCL_SER: 100; R_0402_1005Metric
R_DDC_SDA: 2.2k; R_0402_1005Metric
R_DDC_SDA_SER: 100; R_0402_1005Metric
R_E_OPT_1, R_E_OPT_2, R_E_OPT_3, R_E_OPT_4: 0/DNP; R_0402_1005Metric
R_HUB_BP: 10k; R_0402_1005Metric
R_HUB_RST: 10k; R_0402_1005Metric
R_I2C1_SCL_PU, R_I2C1_SDA_PU: 4.7k; R_0402_1005Metric
R_ILIM_J8, R_ILIM_J9, R_ILIM_J10, R_ILIM_J11: 30k; R_0402_1005Metric
R_INT_PU: 10k; R_0402_1005Metric
R_M2M_PERST: 10k; R_0402_1005Metric
R_MASKROM_PU: 10k; R_0402_1005Metric
R_NVME_ACT_PU: 10k; R_0402_1005Metric
R_PCIE0_TERM_N, R_PCIE0_TERM_P: 49.9 DNP; R_0402_1005Metric
R_POE_CLASS: 12.5 DNP; R_0402_1005Metric
R_POE_SIG: 25k DNP; R_0402_1005Metric
R_PU_PCIE0_CLKREQ, R_PU_PCIE0_PERST, R_PU_PCIE1_CLKREQ, R_PU_PCIE1_PERST: 10k; R_0402_1005Metric
R_PWR_EN_DLY: 100k; R_0402_1005Metric
R_RESET_PU: 10k; R_0402_1005Metric
R_SCL_PU: 4.7k; R_0402_1005Metric
R_SDA_PU: 4.7k; R_0402_1005Metric
SW1: RESET; SW_SPST_TL3305A
SW2: BOOT; SW_SPST_TL3305A
T1: 750317847 DNP; DIP-8_W7.62mm
TP1, TP2, TP3, TP4, TP5: TP; TestPoint_Pad_D1.5mm
U2: RTL8125BG; QFN-64-1EP_9x9mm_P0.5mm_EP4.7x4.7mm
U3: MP2315; SOT-563
U4: AP2112K-3.3; SOT-23-5
U5: CH224K; VSSOP-10_3x3mm_P0.5mm
U6: MP8007 DNP; SOIC-16_3.9x9.9mm_P1.27mm
U7: DS3231MZ+; SOIC-8_3.9x4.9mm_P1.27mm
U10: GL3523; ArtInChip_QFN-88-1EP_10x10mm_P0.4mm_EP6.74x6.74mm
U11, U12, U13, U14: TPS2553; SOT-23-6
U_HDMI_ESD_1, U_HDMI_ESD_2, U_HDMI_ESD_3, U_HDMI_ESD_4: USBLC6-2SC6; SOT-23-6
Y1: 25MHz TCXO; Crystal_SMD_3225-4Pin_3.2x2.5mm
Y_HUB: 25MHz; Crystal_SMD_3225-4Pin_3.2x2.5mm

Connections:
+3V3_AUX: C_BLK_3V3_AUX_01.1, C_BLK_3V3_AUX_02.1, C_BLK_3V3_AUX_03.1, C_DEC_3V3_AUX_01.1, C_DEC_3V3_AUX_02.1, C_DEC_3V3_AUX_03.1, C_DEC_3V3_AUX_04.1, C_DEC_3V3_AUX_05.1, C_DEC_3V3_AUX_06.1, C_DEC_3V3_AUX_07.1, C_DEC_3V3_AUX_08.1, C_DEC_3V3_AUX_09.1, C_DEC_3V3_AUX_10.1, C_HUB_1.1, C_HUB_2.1, C_HUB_3.1, C_HUB_4.1, C_HUB_5.1, C_HUB_6.1, C_HUB_7.1, C_HUB_8.1, C_HUB_BULK.1, C_M2E_1.1, C_M2E_2.1, C_M2E_3.1, C_M2E_BULK.1, C_M2M_1.1, C_M2M_2.1, C_M2M_3.1, C_M2M_4.1, C_M2M_BULK.1, C_RTC_1.1, C_RTC_2.1, C_RTL_1.1, C_RTL_2.1, C_RTL_3.1, C_RTL_4.1, C_RTL_5.1, C_RTL_6.1, C_RTL_BULK.1, D1.1, FB_AVDD_1.1, FB_AVDD_2.1, FB_AVDD_3.1, FB_AVDD_4.1, J5.69, J5.71, J5.73, J5.75, J6.2, J6.4, J6.72, J6.74, J13.1, J13.17, R_BOOT0_PU.1, R_BOOT1_PU.1, R_BOOT2_PU.1, R_DDC_G_1.1, R_DDC_G_2.1, R_DDC_LO_1.1, R_DDC_LO_2.1, R_HUB_BP.1, R_HUB_RST.1, R_I2C1_SCL_PU.1, R_I2C1_SDA_PU.1, R_INT_PU.1, R_M2M_PERST.1, R_MASKROM_PU.1, R_NVME_ACT_PU.1, R_PU_PCIE0_CLKREQ.1, R_PU_PCIE0_PERST.1, R_PU_PCIE1_CLKREQ.1, R_PU_PCIE1_PERST.1, R_RESET_PU.1, R_SCL_PU.1, R_SDA_PU.1, U2.22, U2.23, U2.30, U2.31, U2.40, U2.41, U2.50, U2.51, U7.2
+3V3_AUX1: C16.1, TP4.1, U4.5
+5V: C_BLK_5V_01.1, C_BLK_5V_02.1, C_BLK_5V_03.1, C_BLK_5V_04.1, C_CM5_BULK_1.1, C_CM5_BULK_2.1, C_CM5_BULK_3.1, C_CM5_BULK_4.1, C_CM5_BULK_5.1, C_CM5_BULK_6.1, C_CM5_HF_1.1, C_CM5_HF_2.1, C_CM5_HF_3.1, C_CM5_HF_4.1, C_CM5_HF_5.1, C_CM5_HF_6.1, C_CM5_HF_7.1, C_CM5_HF_8.1, C_CM5_HF_9.1, C_CM5_HF_10.1, C_DEC_5V_01.1, C_DEC_5V_02.1, C_DEC_5V_03.1, C_DEC_5V_04.1, C_DEC_5V_05.1, C_DEC_5V_06.1, C_DEC_5V_07.1, C_DEC_5V_08.1, C_DEC_5V_09.1, C_DEC_5V_10.1, C_DEC_5V_11.1, C_DEC_5V_12.1, FB_HDMI_5V.1, J13.2, J13.4, J15.2, R_DDC_HI_1.1, R_DDC_HI_2.1, R_DDC_SCL.1, R_DDC_SDA.1, R_PWR_EN_DLY.1, U11.1, U11.3, U12.1, U12.3, U13.1, U13.3, U14.1, U14.3, U_HDMI_ESD_1.5, U_HDMI_ESD_2.5, U_HDMI_ESD_3.5, U_HDMI_ESD_4.5
+5V1: C10.1, C11.1, C12.1, C13.1, C15.1, L1.2, R5.1, TP3.1, U4.1, U4.3
BOBSMITH_J3: C_BS_J3.1, R_BS_J3_1.2, R_BS_J3_2.2, R_BS_J3_3.2, R_BS_J3_4.2, R_BS_J3_5.2, R_BS_J3_6.2, R_BS_J3_7.2, R_BS_J3_8.2
BOBSMITH_J4: C_BS_J4.1, R_BS_J4_1.2, R_BS_J4_2.2, R_BS_J4_3.2, R_BS_J4_4.2, R_BS_J4_5.2, R_BS_J4_6.2, R_BS_J4_7.2, R_BS_J4_8.2
CHASSIS_GND: C_BS_J3.2, C_BS_J4.2
CM5_MASKROM: R_MASKROM_PU.2, SW2.1
CM5_POWER_EN: C_PWR_EN_DLY.1, R_PWR_EN_DLY.2
CM5_RUN_N: C_RESET_DB.1, R_RESET_PU.2, SW1.1
ETH0_CT_A: D_POE_1.1, D_POE_3.2
ETH0_CT_B: D_POE_2.1, D_POE_4.2
ETH0_MDI0_N: J3.2, R_BS_J3_2.1
ETH0_MDI0_P: J3.1, R_BS_J3_1.1
ETH0_MDI1_N: J3.6, R_BS_J3_6.1
ETH0_MDI1_P: J3.3, R_BS_J3_3.1
ETH0_MDI2_N: J3.5, R_BS_J3_5.1
ETH0_MDI2_P: J3.4, R_BS_J3_4.1
ETH0_MDI3_N: J3.8, R_BS_J3_8.1
ETH0_MDI3_P: J3.7, R_BS_J3_7.1
ETH1_LED_ACT: D4.1, U2.20
ETH1_MDI0_N: J4.2, R_BS_J4_2.1, U2.2
ETH1_MDI0_P: J4.1, R_BS_J4_1.1, U2.1
ETH1_MDI1_N: J4.6, R_BS_J4_6.1, U2.5
ETH1_MDI1_P: J4.3, R_BS_J4_3.1, U2.4
ETH1_MDI2_N: J4.5, R_BS_J4_5.1, U2.8
ETH1_MDI2_P: J4.4, R_BS_J4_4.1, U2.7
ETH1_MDI3_N: J4.8, R_BS_J4_8.1, U2.11
ETH1_MDI3_P: J4.7, R_BS_J4_7.1, U2.10
GND: BT1.2, C_AVDD_BULK_1.2, C_AVDD_BULK_2.2, C_AVDD_BULK_3.2, C_AVDD_BULK_4.2, C_AVDD_HF_1.2, C_AVDD_HF_2.2, C_AVDD_HF_3.2, C_AVDD_HF_4.2, C_BAT_1.2, C_BLK_3V3_AUX_01.2, C_BLK_3V3_AUX_02.2, C_BLK_3V3_AUX_03.2, C_BLK_5V_01.2, C_BLK_5V_02.2, C_BLK_5V_03.2, C_BLK_5V_04.2, C_CM5_BULK_1.2, C_CM5_BULK_2.2, C_CM5_BULK_3.2, C_CM5_BULK_4.2, C_CM5_BULK_5.2, C_CM5_BULK_6.2, C_CM5_HF_1.2, C_CM5_HF_2.2, C_CM5_HF_3.2, C_CM5_HF_4.2, C_CM5_HF_5.2, C_CM5_HF_6.2, C_CM5_HF_7.2, C_CM5_HF_8.2, C_CM5_HF_9.2, C_CM5_HF_10.2, C_DEC_3V3_AUX_01.2, C_DEC_3V3_AUX_02.2, C_DEC_3V3_AUX_03.2, C_DEC_3V3_AUX_04.2, C_DEC_3V3_AUX_05.2, C_DEC_3V3_AUX_06.2, C_DEC_3V3_AUX_07.2, C_DEC_3V3_AUX_08.2, C_DEC_3V3_AUX_09.2, C_DEC_3V3_AUX_10.2, C_DEC_5V_01.2, C_DEC_5V_02.2, C_DEC_5V_03.2, C_DEC_5V_04.2, C_DEC_5V_05.2, C_DEC_5V_06.2, C_DEC_5V_07.2, C_DEC_5V_08.2, C_DEC_5V_09.2, C_DEC_5V_10.2, C_DEC_5V_11.2, C_DEC_5V_12.2, C_EMI.1, C_HUB_1.2, C_HUB_2.2, C_HUB_3.2, C_HUB_4.2, C_HUB_5.2, C_HUB_6.2, C_HUB_7.2, C_HUB_8.2, C_HUB_BULK.2, C_HUB_LDO.2, C_M2E_1.2, C_M2E_2.2, C_M2E_3.2, C_M2E_BULK.2, C_M2M_1.2, C_M2M_2.2, C_M2M_3.2, C_M2M_4.2, C_M2M_BULK.2, C_POE_SEC.2, C_PWR_EN_DLY.2, C_RESET_DB.2, C_RTC_1.2, C_RTC_2.2, C_RTL_1.2, C_RTL_2.2, C_RTL_3.2, C_RTL_4.2, C_RTL_5.2, C_RTL_6.2, C_RTL_BULK.2, C_VB_J8.2, C_VB_J9.2, C_VB_J10.2, C_VB_J11.2, C_VIN_BULK.2, C_VIN_HF.2, D_HDMI_CTL_1.2, D_HDMI_CTL_2.2, D_TVS_J8.2, D_TVS_J9.2, D_TVS_J10.2, D_TVS_J11.2, J5.70, J5.72, J5.74, J6.1, J6.7, J6.9, J6.11, J6.15, J6.17, J6.19, J6.25, J6.33, J6.39, J6.45, J6.51, J6.57, J6.63, J6.69, J6.75, J8.4, J8.10, J9.4, J9.10, J10.4, J10.10, J11.4, J11.10, J12.2, J12.5, J12.8, J12.11, J12.17, J12.SH, J13.6, J13.9, J13.14, J13.20, J13.25, J13.30, J13.34, J13.39, J15.1, R_D1.2, R_D2.2, R_D3.2, R_D4.2, R_D5.2, R_ILIM_J8.2, R_ILIM_J9.2, R_ILIM_J10.2, R_ILIM_J11.2, SW1.2, SW2.2, T1.5, U2.3, U2.6, U2.9, U2.12, U2.14, U2.17, U2.24, U2.29, U2.32, U2.39, U2.42, U2.49, U2.52, U2.60, U7.5, U11.2, U12.2, U13.2, U14.2, U_HDMI_ESD_1.2, U_HDMI_ESD_2.2, U_HDMI_ESD_3.2, U_HDMI_ESD_4.2
GND1: C1.2, C2.2, C3.2, C5.2, C6.2, C10.2, C11.2, C12.2, C13.2, C15.2, C16.2, D6.2, J7.A1, J7.A12, J7.B1, J7.B12, J7.S1, R1.2, R2.2, R3.2, R6.2, TP5.1, U3.4, U4.2, U5.8
HDMI_CEC: D_HDMI_CTL_1.1, J12.13
HDMI_CLK_N: J12.12, U_HDMI_ESD_4.3, U_HDMI_ESD_4.4
HDMI_CLK_P: J12.10, U_HDMI_ESD_4.1, U_HDMI_ESD_4.6
HDMI_DDC_SCL: J12.15, R_DDC_LO_2.2, R_DDC_SCL.2
HDMI_DDC_SDA: J12.16, R_DDC_LO_1.2, R_DDC_SDA.2
HDMI_HPD: D_HDMI_CTL_2.1, J12.19
HDMI_TX0_N: J12.9, U_HDMI_ESD_1.3, U_HDMI_ESD_1.4
HDMI_TX0_P: J12.7, U_HDMI_ESD_1.1, U_HDMI_ESD_1.6
HDMI_TX1_N: J12.6, U_HDMI_ESD_2.3, U_HDMI_ESD_2.4
HDMI_TX1_P: J12.4, U_HDMI_ESD_2.1, U_HDMI_ESD_2.6
HDMI_TX2_N: J12.3, U_HDMI_ESD_3.3, U_HDMI_ESD_3.4
HDMI_TX2_P: J12.1, U_HDMI_ESD_3.1, U_HDMI_ESD_3.6
I2C0_SCL: R_SCL_PU.2, U7.8
I2C0_SDA: R_SDA_PU.2, U7.7
unnamed: R1.1, U5.5
unnamed: R2.1, U5.6
unnamed: R3.1, U5.7
unnamed: R4.2, U3.6
unnamed: C4.1, U3.1
unnamed: R5.2, R6.1, U3.5
unnamed: C6.1, R7.1
unnamed: C5.1, R7.2
unnamed: U2.15, Y1.1
unnamed: U2.16, Y1.2
unnamed: R_ILIM_J8.1, U11.6
unnamed: R_ILIM_J9.1, U12.6
unnamed: R_ILIM_J10.1, U13.6
unnamed: R_ILIM_J11.1, U14.6
unnamed: R_POE_CLASS.1, U6.3
unnamed: BT1.1, D_BAT.1
unnamed: D1.2, R_D1.1
unnamed: D2.2, R_D2.1
unnamed: D3.2, R_D3.1
unnamed: D4.2, R_D4.1
unnamed: D5.2, R_D5.1
NVME_ACT_N: D5.1, J5.11, R_NVME_ACT_PU.2
PCIE0_CLKREQ_N: J5.52, R_PU_PCIE0_CLKREQ.2
PCIE0_PERST_N: J5.50, R_M2M_PERST.2, R_PU_PCIE0_PERST.2
PCIE0_REFCLK_N: J5.25, R_PCIE0_TERM_N.1
PCIE0_REFCLK_P: J5.27, R_PCIE0_TERM_P.1
PCIE1_CLKREQ_N: J6.50, R_PU_PCIE1_CLKREQ.2, U2.64
PCIE1_PERST_N: J6.56, R_PU_PCIE1_PERST.2, U2.63
PCIE1_RX_N: R_E_OPT_4.2, U2.59
PCIE1_RX_P: R_E_OPT_3.2, U2.58
PCIE1_TX_N: R_E_OPT_2.2, U2.56
PCIE1_TX_P: R_E_OPT_1.2, U2.55
POE_VIN_POS: C_POE_BULK.1, C_POE_HF.1, D_POE_1.2, D_POE_2.2, D_POE_TVS.1, R_POE_SIG.1, T1.1, U6.1
PoE_GND: C_POE_BULK.2, C_POE_HF.2, D_POE_3.1, D_POE_4.1, D_POE_TVS.2, R_POE_CLASS.2, R_POE_SIG.2, U6.2, U6.4, U6.16
RTC_INT_N: R_INT_PU.2, U7.3
SW_5V: C4.2, L1.1, U3.3
USB_CC1: J7.A5, U5.3
USB_CC2: J7.B5, U5.4
USB_DM1: J7.A7, J7.B7, U5.10
USB_DP1: J7.A6, J7.B6, U5.9
VBUS_J8: C_VB_J8.1, D_TVS_J8.1, J8.1, U11.4
VBUS_J9: C_VB_J9.1, D_TVS_J9.1, J9.1, U12.4
VBUS_J10: C_VB_J10.1, D_TVS_J10.1, J10.1, U13.4
VBUS_J11: C_VB_J11.1, D_TVS_J11.1, J11.1, U14.4
VBUS_USB1: C1.1, D6.1, J7.A4, J7.A9, J7.B4, J7.B9, TP1.1, U5.1
VIN_12V: C_VIN_BULK.1, C_VIN_HF.1, D_POE_OR.2
VIN_12V1: C2.1, C3.1, R4.1, TP2.1, U3.2, U5.2
V_BAT: C_BAT_1.1, D_BAT.2, U7.6
__NC__1: J5.1, J5.2, J5.3, J5.4, J5.5, J5.6, J5.7, J5.8, J5.9, J5.10, J5.12, J5.13, J5.14, J5.15, J5.16, J5.17, J5.18, J5.19, J5.20, J5.21, J5.22, J5.23, J5.24, J5.26, J5.28, J5.30, J5.32, J5.34, J5.36, J5.37, J5.38, J5.39, J5.40, J5.41, J5.42, J5.43, J5.44, J5.45, J5.46, J5.47, J5.48, J5.49, J5.51, J5.53, J5.55, J5.56, J5.57, J5.58, J5.59, J5.60, J5.61, J5.62, J5.63, J5.64, J5.65, J5.66, J5.67, J5.68, J6.3, J6.5, J6.6, J6.8, J6.10, J6.12, J6.13, J6.14, J6.16, J6.18, J6.20, J6.22, J6.24, J6.26, J6.27, J6.28, J6.30, J6.32, J6.34, J6.35, J6.37, J6.40, J6.42, J6.44, J6.47, J6.49, J6.52, J6.53, J6.54, J6.55, J6.58, J6.59, J6.60, J6.61, J6.62, J6.64, J6.65, J6.66, J6.67, J6.68, J6.70, J6.71, J6.73

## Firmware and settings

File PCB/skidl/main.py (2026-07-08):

"""
NodePad — Main schematic composition (FULL design).

Composes all sub-blocks into a single design and emits the KiCad netlist.

Sub-blocks:
    power_tree.py     Power (USB-C -> PD -> buck -> LDO)
    cm5.py            Radxa CM5 SoM connectors J1/J2
    ethernet.py       RJ45 #1 (1G native) + RTL8125 + RJ45 #2 (2.5G)
    usb_hub.py        GL3523 hub + 4x USB-A + TPS2553 power switches
    m2.py             M.2 M-key NVMe + M.2 E-key WiFi
    hdmi.py           HDMI 2.0 Type-A + ESD
    poe.py            PoE+ front-end (all DNP by default)
    rtc.py            DS3231 + CR2032 backup
    user_io.py        Buttons, LEDs, GPIO40, fan header

Run:
    KICAD_SYMBOL_DIR=/opt/kicad-libs/symbols \\
    python3 main.py

Outputs:
    ./netlists/nodepad.net
"""

import os
os.environ.setdefault("KICAD_SYMBOL_DIR", "/opt/kicad-libs/symbols")
os.environ.setdefault("KICAD9_SYMBOL_DIR", "/opt/kicad-libs/symbols")

from skidl import Net, generate_netlist, ERC, set_default_tool, KICAD9

set_default_tool(KICAD9)


# ---------------------------------------------------------------------------
# Declare every net that crosses sub-block boundaries FIRST
# so sub-blocks all bind to the same instance.
# ---------------------------------------------------------------------------
def make_net(name, drive=None):
    n = Net(name)
    if drive is not None:
        n.drive = drive
    return n


nets = {
    # Power rails (already created by power_tree - we'll reuse by name)
    "GND":       make_net("GND", drive=3),
    "+5V":       make_net("+5V"),
    "+3V3_AUX":  make_net("+3V3_AUX"),
    "VIN_12V":   make_net("VIN_12V"),
    "VBUS_USB":  make_net("VBUS_USB"),

    # USB 2.0 (OTG) and USB 3.0 host (CM5)
    "USB_DP":    make_net("USB_DP"),
    "USB_DM":    make_net("USB_DM"),
    "USB3_TX_P": make_net("USB3_TX_P"),
    "USB3_TX_N": make_net("USB3_TX_N"),
    "USB3_RX_P": make_net("USB3_RX_P"),
    "USB3_RX_N": make_net("USB3_RX_N"),
    "USB3_DP":   make_net("USB3_DP"),
    "USB3_DM":   make_net("USB3_DM"),
    "USB2_1_DP": make_net("USB2_1_DP"),
    "USB2_1_DM": make_net("USB2_1_DM"),
    "USB2_2_DP": make_net("USB2_2_DP"),
    "USB2_2_DM": make_net("USB2_2_DM"),

    # I²C busses
    "I2C0_SDA":  make_net("I2C0_SDA"),
    "I2C0_SCL":  make_net("I2C0_SCL"),
    "I2C1_SDA":  make_net("I2C1_SDA"),
    "I2C1_SCL":  make_net("I2C1_SCL"),

    # UART
    "UART0_TX":  make_net("UART0_TX"),
    "UART0_RX":  make_net("UART0_RX"),
    "UART2_TX":  make_net("UART2_TX"),
    "UART2_RX":  make_net("UART2_RX"),

    # SPI
    "SPI0_MOSI": make_net("SPI0_MOSI"),
    "SPI0_MISO": make_net("SPI0_MISO"),
    "SPI0_SCLK": make_net("SPI0_SCLK"),
    "SPI0_CE0":  make_net("SPI0_CE0"),
    "SPI0_CE1":  make_net("SPI0_CE1"),

    # PWM
    "PWM_GPIO_1": make_net("PWM_GPIO_1"),
    "PWM_GPIO_2": make_net("PWM_GPIO_2"),

    # HDMI (CM5 -> J12)
    "HDMI_TX0_P": make_net("HDMI_TX0_P"),
    "HDMI_TX0_N": make_net("HDMI_TX0_N"),
    "HDMI_TX1_P": make_net("HDMI_TX1_P"),
    "HDMI_TX1_N": make_net("HDMI_TX1_N"),
    "HDMI_TX2_P": make_net("HDMI_TX2_P"),
    "HDMI_TX2_N": make_net("HDMI_TX2_N"),
    "HDMI_CLK_P": make_net("HDMI_CLK_P"),
    "HDMI_CLK_N": make_net("HDMI_CLK_N"),
    "HDMI_CEC":   make_net("HDMI_CEC"),
    "HDMI_HPD":   make_net("HDMI_HPD"),
    "HDMI_DDC_SDA": make_net("HDMI_DDC_SDA"),
    "HDMI_DDC_SCL": make_net("HDMI_DDC_SCL"),

    # Ethernet #1 (CM5 native GbE MDI)
    "ETH0_MDI0_P": make_net("ETH0_MDI0_P"),
    "ETH0_MDI0_N": make_net("ETH0_MDI0_N"),
    "ETH0_MDI1_P": make_net("ETH0_MDI1_P"),
    "ETH0_MDI1_N": make_net("ETH0_MDI1_N"),
    "ETH0_MDI2_P": make_net("ETH0_MDI2_P"),
    "ETH0_MDI2_N": make_net("ETH0_MDI2_N"),
    "ETH0_MDI3_P": make_net("ETH0_MDI3_P"),
    "ETH0_MDI3_N": make_net("ETH0_MDI3_N"),
    "ETH0_LED_ACT":  make_net("ETH0_LED_ACT"),
    "ETH0_LED_LINK": make_net("ETH0_LED_LINK"),

    # Ethernet #2 (RTL8125 MDI + LEDs)
    "ETH1_MDI0_P": make_net("ETH1_MDI0_P"),
    "ETH1_MDI0_N": make_net("ETH1_MDI0_N"),
    "ETH1_MDI1_P": make_net("ETH1_MDI1_P"),
    "ETH1_MDI1_N": make_net("ETH1_MDI1_N"),
    "ETH1_MDI2_P": make_net("ETH1_MDI2_P"),
    "ETH1_MDI2_N": make_net("ETH1_MDI2_N"),
    "ETH1_MDI3_P": make_net("ETH1_MDI3_P"),
    "ETH1_MDI3_N": make_net("ETH1_MDI3_N"),
    "ETH1_LED_ACT":  make_net("ETH1_LED_ACT"),
    "ETH1_LED_LINK": make_net("ETH1_LED_LINK"),

    # PCIe Combo0 (M-key NVMe)
    "PCIE0_TX_P":     make_net("PCIE0_TX_P"),
    "PCIE0_TX_N":     make_net("PCIE0_TX_N"),
    "PCIE0_RX_P":     make_net("PCIE0_RX_P"),
    "PCIE0_RX_N":     make_net("PCIE0_RX_N"),
    "PCIE0_REFCLK_P": make_net("PCIE0_REFCLK_P"),
    "PCIE0_REFCLK_N": make_net("PCIE0_REFCLK_N"),
    "PCIE0_PERST_N":  make_net("PCIE0_PERST_N"),
    "PCIE0_CLKREQ_N": make_net("PCIE0_CLKREQ_N"),
    "PCIE0_WAKE_N":   make_net("PCIE0_WAKE_N"),

    # PCIe Combo1 (E-key or RTL8125)
    "PCIE1_TX_P":     make_net("PCIE1_TX_P"),
    "PCIE1_TX_N":     make_net("PCIE1_TX_N"),
    "PCIE1_RX_P":     make_net("PCIE1_RX_P"),
    "PCIE1_RX_N":     make_net("PCIE1_RX_N"),
    "PCIE1_REFCLK_P": make_net("PCIE1_REFCLK_P"),
    "PCIE1_REFCLK_N": make_net("PCIE1_REFCLK_N"),
    "PCIE1_PERST_N":  make_net("PCIE1_PERST_N"),
    "PCIE1_CLKREQ_N": make_net("PCIE1_CLKREQ_N"),
    "PCIE1_WAKE_N":   make_net("PCIE1_WAKE_N"),

    # SD card + boot select
    "SD_CLK": make_net("SD_CLK"),
    "SD_CMD": make_net("SD_CMD"),
    "SD_D0":  make_net("SD_D0"),
    "SD_D1":  make_net("SD_D1"),
    "SD_D2":  make_net("SD_D2"),
    "SD_D3":  make_net("SD_D3"),
    "SD_DET_N": make_net("SD_DET_N"),
    "CM5_BOOT0": make_net("CM5_BOOT0"),
    "CM5_BOOT1": make_net("CM5_BOOT1"),
    "CM5_BOOT2": make_net("CM5_BOOT2"),

    # CM5 control signals
    "CM5_RUN_N":       make_net("CM5_RUN_N"),
    "CM5_MASKROM":     make_net("CM5_MASKROM"),
    "CM5_POWER_EN":    make_net("CM5_POWER_EN"),
    "CM5_PWR_GOOD":    make_net("CM5_PWR_GOOD"),
    "CM5_GPIO_STATUS": make_net("CM5_GPIO_STATUS"),

    # I/O signals (fan, buttons already-known)
    "FAN_TACH": make_net("FAN_TACH"),
    "FAN_PWM":  make_net("FAN_PWM"),
    "NVME_ACT_N": make_net("NVME_ACT_N"),
    "RTC_INT_N":  make_net("RTC_INT_N"),

    # Aliases used by user_io.build()
    "PHY1_LED_ACT": None,  # will be aliased to ETH0_LED_ACT below
    "PHY2_LED_ACT": None,
}
# Alias PHYx_LED_ACT -> ETHx_LED_ACT
nets["PHY1_LED_ACT"] = nets["ETH0_LED_ACT"]
nets["PHY2_LED_ACT"] = nets["ETH1_LED_ACT"]


# ---------------------------------------------------------------------------
# Instantiate sub-blocks in dependency order
# ---------------------------------------------------------------------------

# Power tree runs on import (still uses its own local Net() instances but
# de-duplicates by name — the top-level nets we made above will merge in
# because Net() with same name = same net).
import power_tree  # noqa: F401

# CM5 SoM connectors
import cm5
cm5.build(nets)

# Ethernet
import ethernet
ethernet.build(nets)

# USB hub + 4x USB-A
import usb_hub
usb_hub.build(nets)

# M.2 slots
import m2
m2.build(nets)

# HDMI
import hdmi
hdmi.build(nets)

# PoE (optional, all DNP)
import poe
poe.build(nets)

# RTC
import rtc
rtc.build(V3P3=nets["+3V3_AUX"], GND=nets["GND"],
          SDA=nets["I2C0_SDA"], SCL=nets["I2C0_SCL"],
          INT_N=nets["RTC_INT_N"])

# User I/O
import user_io
user_io.build(
    V3P3=nets["+3V3_AUX"],
    V5=nets["+5V"],
    GND=nets["GND"],
    SIGNALS={
        "RESET_N":   nets["CM5_RUN_N"],
        "RECOVERY":  nets["CM5_MASKROM"],
        "LED_SYS":   nets["CM5_GPIO_STATUS"],
        "LED_LNK1":  nets["ETH0_LED_ACT"],
        "LED_LNK2":  nets["ETH1_LED_ACT"],
        "LED_NVME":  nets["NVME_ACT_N"],
        "FAN_TACH":  nets["FAN_TACH"],
        "FAN_PWM":   nets["FAN_PWM"],
    },
)


# Extras (heatsink mount, HDMI level shifter, more decoupling)
import extras
extras.build(nets)


import missing_parts
missing_parts.build(nets)


# ---------------------------------------------------------------------------
# Emit netlist
# ---------------------------------------------------------------------------
if __name__ == "__main__":
    os.makedirs("netlists", exist_ok=True)
    ERC()
    generate_netlist(file_="netlists/nodepad.net")
    print("[OK] Combined netlist -> netlists/nodepad.net")

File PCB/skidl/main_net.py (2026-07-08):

"""
NodePad-Net — Networking variant main.

Same base as NodePad but with:
  * 2× 2.5 GbE (adds a second RTL8125BG on PCIe1)
  * 1× SFP cage (1G fiber uplink over SGMII)
  * 1× 1 GbE (CM5 native, kept for management)
  * NO M.2 E-key slot (PCIe1 goes to RTL8125-2 instead of WiFi)
  * Trimmed USB: 2× USB-A instead of 4× (more room for RJ45s + SFP)
  * NO HDMI (headless router/switch appliance)

Everything else identical to the base NodePad:
  * Radxa CM5 SoM
  * USB-C PD input, MP2315 buck, AP2112 LDO
  * M.2 M-key 2280 NVMe (still important for boot storage)
  * RTC + coin cell
  * Buttons + LEDs + fan + heatsink mounts

Run:
    KICAD_SYMBOL_DIR=/opt/kicad-libs/symbols python3 main_net.py

Outputs:
    netlists/nodepad_net.net
"""

import os
os.environ.setdefault("KICAD_SYMBOL_DIR", "/opt/kicad-libs/symbols")
os.environ.setdefault("KICAD9_SYMBOL_DIR", "/opt/kicad-libs/symbols")

from skidl import Net, generate_netlist, ERC, set_default_tool, KICAD9

set_default_tool(KICAD9)


def make_net(name, drive=None):
    n = Net(name)
    if drive is not None:
        n.drive = drive
    return n


# Same shared nets as main.py
nets = {
    "GND":       make_net("GND", drive=3),
    "+5V":       make_net("+5V"),
    "+3V3_AUX":  make_net("+3V3_AUX"),
    "VIN_12V":   make_net("VIN_12V"),
    "VBUS_USB":  make_net("VBUS_USB"),
    "USB_DP":    make_net("USB_DP"),
    "USB_DM":    make_net("USB_DM"),
    "USB3_TX_P": make_net("USB3_TX_P"),
    "USB3_TX_N": make_net("USB3_TX_N"),
    "USB3_RX_P": make_net("USB3_RX_P"),
    "USB3_RX_N": make_net("USB3_RX_N"),
    "USB3_DP":   make_net("USB3_DP"),
    "USB3_DM":   make_net("USB3_DM"),
    "USB2_1_DP": make_net("USB2_1_DP"),
    "USB2_1_DM": make_net("USB2_1_DM"),
    "USB2_2_DP": make_net("USB2_2_DP"),
    "USB2_2_DM": make_net("USB2_2_DM"),
    "I2C0_SDA":  make_net("I2C0_SDA"),
    "I2C0_SCL":  make_net("I2C0_SCL"),
    "I2C1_SDA":  make_net("I2C1_SDA"),
    "I2C1_SCL":  make_net("I2C1_SCL"),
    "UART0_TX":  make_net("UART0_TX"),
    "UART0_RX":  make_net("UART0_RX"),
    "UART2_TX":  make_net("UART2_TX"),
    "UART2_RX":  make_net("UART2_RX"),
    "SPI0_MOSI": make_net("SPI0_MOSI"),
    "SPI0_MISO": make_net("SPI0_MISO"),
    "SPI0_SCLK": make_net("SPI0_SCLK"),
    "SPI0_CE0":  make_net("SPI0_CE0"),
    "SPI0_CE1":  make_net("SPI0_CE1"),
    "PWM_GPIO_1": make_net("PWM_GPIO_1"),
    "PWM_GPIO_2": make_net("PWM_GPIO_2"),

    # HDMI nets exist so cm5.py can reference them; unused in this variant
    "HDMI_TX0_P": make_net("HDMI_TX0_P"),
    "HDMI_TX0_N": make_net("HDMI_TX0_N"),
    "HDMI_TX1_P": make_net("HDMI_TX1_P"),
    "HDMI_TX1_N": make_net("HDMI_TX1_N"),
    "HDMI_TX2_P": make_net("HDMI_TX2_P"),
    "HDMI_TX2_N": make_net("HDMI_TX2_N"),
    "HDMI_CLK_P": make_net("HDMI_CLK_P"),
    "HDMI_CLK_N": make_net("HDMI_CLK_N"),
    "HDMI_CEC":   make_net("HDMI_CEC"),
    "HDMI_HPD":   make_net("HDMI_HPD"),
    "HDMI_DDC_SDA": make_net("HDMI_DDC_SDA"),
    "HDMI_DDC_SCL": make_net("HDMI_DDC_SCL"),

    # Ethernet #1 native GbE
    "ETH0_MDI0_P": make_net("ETH0_MDI0_P"),
    "ETH0_MDI0_N": make_net("ETH0_MDI0_N"),
    "ETH0_MDI1_P": make_net("ETH0_MDI1_P"),
    "ETH0_MDI1_N": make_net("ETH0_MDI1_N"),
    "ETH0_MDI2_P": make_net("ETH0_MDI2_P"),
    "ETH0_MDI2_N": make_net("ETH0_MDI2_N"),
    "ETH0_MDI3_P": make_net("ETH0_MDI3_P"),
    "ETH0_MDI3_N": make_net("ETH0_MDI3_N"),
    "ETH0_LED_ACT":  make_net("ETH0_LED_ACT"),
    "ETH0_LED_LINK": make_net("ETH0_LED_LINK"),

    # Ethernet #2 (first RTL8125, shares Combo0 - wait, we need it on its own lane)
    # Actually for this variant we keep #2 on Combo0 (shared with NVMe? No, dedicate)
    # Simpler: keep ethernet.py's RTL8125 on PCIE1 (its default),
    # AND add a second RTL8125 also on PCIE1 via a PCIe switch OR use PCIE0 for one of them.
    # For rev1 scaffold: repurpose Combo0 to a PCIe switch chip if needed.
    # For now, both RTL8125s share PCIE1 declaration but note in comment.
    "ETH1_MDI0_P": make_net("ETH1_MDI0_P"),
    "ETH1_MDI0_N": make_net("ETH1_MDI0_N"),
    "ETH1_MDI1_P": make_net("ETH1_MDI1_P"),
    "ETH1_MDI1_N": make_net("ETH1_MDI1_N"),
    "ETH1_MDI2_P": make_net("ETH1_MDI2_P"),
    "ETH1_MDI2_N": make_net("ETH1_MDI2_N"),
    "ETH1_MDI3_P": make_net("ETH1_MDI3_P"),
    "ETH1_MDI3_N": make_net("ETH1_MDI3_N"),
    "ETH1_LED_ACT":  make_net("ETH1_LED_ACT"),
    "ETH1_LED_LINK": make_net("ETH1_LED_LINK"),

    # Ethernet #3 - second 2.5G RTL8125
    "ETH2_MDI0_P": make_net("ETH2_MDI0_P"),
    "ETH2_MDI0_N": make_net("ETH2_MDI0_N"),
    "ETH2_MDI1_P": make_net("ETH2_MDI1_P"),
    "ETH2_MDI1_N": make_net("ETH2_MDI1_N"),
    "ETH2_MDI2_P": make_net("ETH2_MDI2_P"),
    "ETH2_MDI2_N": make_net("ETH2_MDI2_N"),
    "ETH2_MDI3_P": make_net("ETH2_MDI3_P"),
    "ETH2_MDI3_N": make_net("ETH2_MDI3_N"),
    "ETH2_LED_ACT":  make_net("ETH2_LED_ACT"),
    "ETH2_LED_LINK": make_net("ETH2_LED_LINK"),

    # SFP
    "SFP_TX_P": make_net("SFP_TX_P"),
    "SFP_TX_N": make_net("SFP_TX_N"),
    "SFP_RX_P": make_net("SFP_RX_P"),
    "SFP_RX_N": make_net("SFP_RX_N"),

    # PCIe Combo0 (M-key NVMe)
    "PCIE0_TX_P":     make_net("PCIE0_TX_P"),
    "PCIE0_TX_N":     make_net("PCIE0_TX_N"),
    "PCIE0_RX_P":     make_net("PCIE0_RX_P"),
    "PCIE0_RX_N":     make_net("PCIE0_RX_N"),
    "PCIE0_REFCLK_P": make_net("PCIE0_REFCLK_P"),
    "PCIE0_REFCLK_N": make_net("PCIE0_REFCLK_N"),
    "PCIE0_PERST_N":  make_net("PCIE0_PERST_N"),
    "PCIE0_CLKREQ_N": make_net("PCIE0_CLKREQ_N"),
    "PCIE0_WAKE_N":   make_net("PCIE0_WAKE_N"),

    # PCIe Combo1 (both RTL8125s share via bifurcation OR one goes here)
    "PCIE1_TX_P":     make_net("PCIE1_TX_P"),
    "PCIE1_TX_N":     make_net("PCIE1_TX_N"),
    "PCIE1_RX_P":     make_net("PCIE1_RX_P"),
    "PCIE1_RX_N":     make_net("PCIE1_RX_N"),
    "PCIE1_REFCLK_P": make_net("PCIE1_REFCLK_P"),
    "PCIE1_REFCLK_N": make_net("PCIE1_REFCLK_N"),
    "PCIE1_PERST_N":  make_net("PCIE1_PERST_N"),
    "PCIE1_CLKREQ_N": make_net("PCIE1_CLKREQ_N"),
    "PCIE1_WAKE_N":   make_net("PCIE1_WAKE_N"),

    # SD + boot
    "SD_CLK": make_net("SD_CLK"),
    "SD_CMD": make_net("SD_CMD"),
    "SD_D0":  make_net("SD_D0"),
    "SD_D1":  make_net("SD_D1"),
    "SD_D2":  make_net("SD_D2"),
    "SD_D3":  make_net("SD_D3"),
    "SD_DET_N": make_net("SD_DET_N"),
    "CM5_BOOT0": make_net("CM5_BOOT0"),
    "CM5_BOOT1": make_net("CM5_BOOT1"),
    "CM5_BOOT2": make_net("CM5_BOOT2"),

    # CM5 control
    "CM5_RUN_N":       make_net("CM5_RUN_N"),
    "CM5_MASKROM":     make_net("CM5_MASKROM"),
    "CM5_POWER_EN":    make_net("CM5_POWER_EN"),
    "CM5_PWR_GOOD":    make_net("CM5_PWR_GOOD"),
    "CM5_GPIO_STATUS": make_net("CM5_GPIO_STATUS"),

    "FAN_TACH": make_net("FAN_TACH"),
    "FAN_PWM":  make_net("FAN_PWM"),
    "NVME_ACT_N": make_net("NVME_ACT_N"),
    "RTC_INT_N":  make_net("RTC_INT_N"),
}


# ----- Compose the -Net variant -------------------------------------

import power_tree      # noqa: F401  (auto-instantiates on import)
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

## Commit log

2026-07-06 feat: update project details for Samrath "Sami" Singh
    [Macropad from hackpad.kicad_pcb, Macropad from hackpad.kicad_sch]
2026-07-06 rename: correct file extensions in CAD and Production directories
    Updated website URL in README
2026-07-06 feat: add renders, schematic, and PCB layout images
2026-07-07 auto-commit for 4fa4760e-a6d4-472f-b7a7-c3b9f8ff6a78
    [Macropad from hackpad.kicad_pcb]
2026-07-07 auto-commit for 41c073d8-9196-446b-9482-faa2dd3c32da
    [Back Case.step, Front Case.step, Key Switch Spacer.step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]
2026-07-08 auto-commit for a16a7665-2299-4921-b635-0f75cfdfa091
    [Back Case.step, Front Case.step, Key Switch Spacer.step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]
2026-07-08 auto-commit for 915485eb-2753-47f8-a84c-bf339ea339fb
    [BOM.csv, NodePad.kicad_pcb, NodePad.kicad_sch]
2026-07-08 auto-commit for 1e42cf4f-3af1-430f-b4bd-a55f7dad9cb4
    [NodePad.kicad_pcb]
2026-07-08 Auto-generated changes
    [NodePad-B_Cu.gbr, NodePad-B_Mask.gbr, NodePad-B_Paste.gbr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]
2026-07-08 Update website: 3D PCB model, scroll disassembly, nojekyll fix
2026-07-08 Fix PCB board position, photorealistic materials, reduced scroll rotation
2026-07-08 Match button styles, wire all notify buttons to mailto
2026-07-08 Notify buttons: copy email to clipboard with toast, mailto as fallback
2026-07-08 Replace contact form with single copy-email button
2026-07-08 Replace procedural model with real KiCad GLB export
2026-07-11 refactor: relocate components and add net assignments on PCB/NodePad.kicad_pcb
    [NodePad.kicad_pcb]

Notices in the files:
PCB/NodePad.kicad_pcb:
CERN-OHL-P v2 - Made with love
